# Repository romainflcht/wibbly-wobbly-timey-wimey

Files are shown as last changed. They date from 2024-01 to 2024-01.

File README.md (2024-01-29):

# Wibbly-Wobbly-Timey-Wimey

<p align="center">
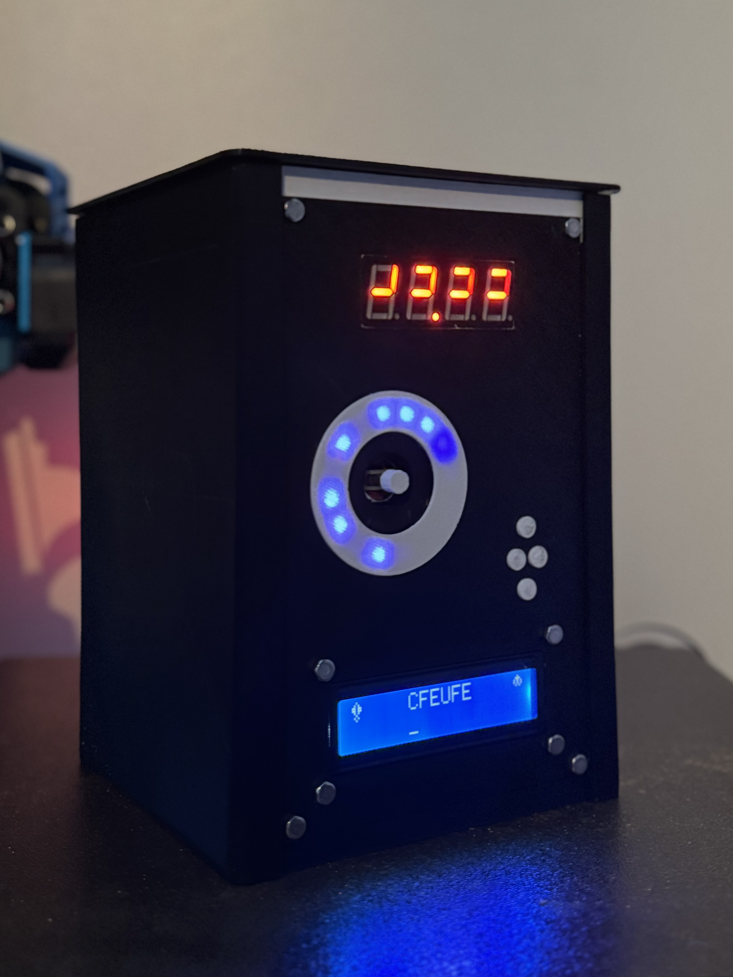
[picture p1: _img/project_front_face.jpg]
A picture of the project
  
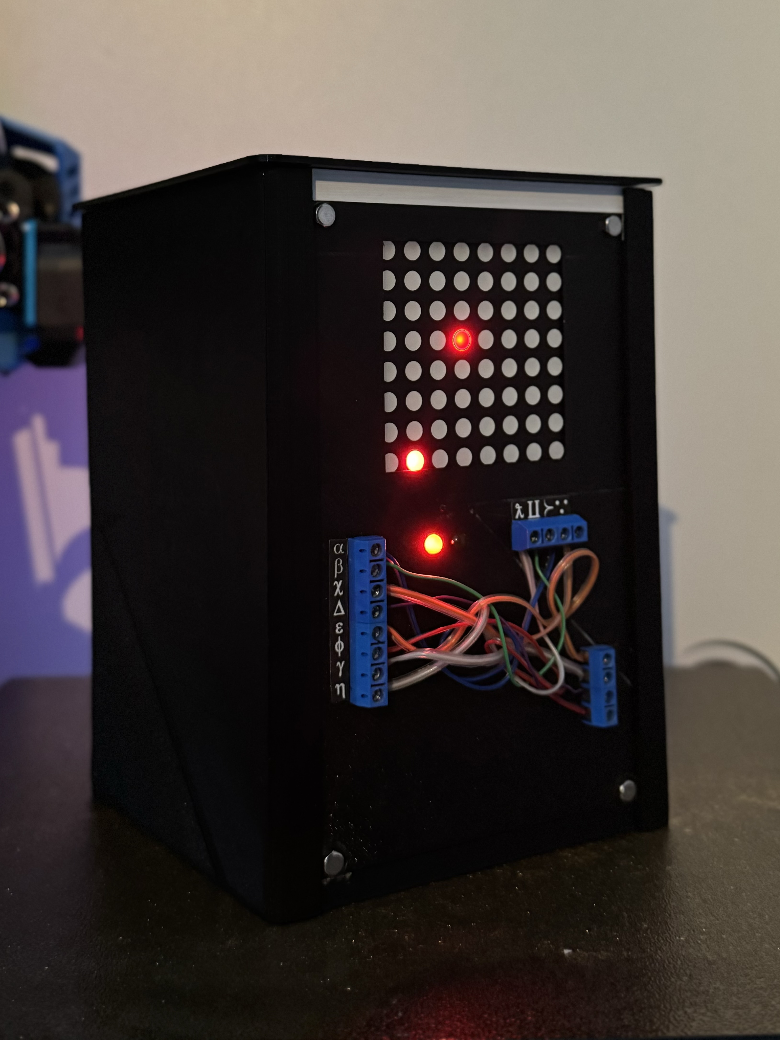
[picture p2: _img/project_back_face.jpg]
A picture of the project
  
  <br />
  <i>The TARDIS that need to be defused.</i>
</p>
<br />

<div style="text-align: justify">
"Wibbly-Wobbly Timey-Wimey" is a bomb defusal escape game inspired by the popular television series <a href="https://fr.wikipedia.org/wiki/Doctor_Who" target="_blank">Doctor Who</a>. This game draws inspiration from the mechanics of <a href="https://keeptalkinggame.com/" target="_blank">Keep Talking And Nobody Explodes</a>. The primary objective of our game is to defuse the TARDIS by solving four small puzzles within a 45-minute time limit. To assist players in resolving these puzzles, the game includes a documentation guide.
</div>

## The project
<div style="text-align: justify">
This project is an engineering school assignment completed over one semester in groups of three. The instructions for this project were to create something playable, drawing inspiration from a movie or a series. Given my strong interest in escape games, the idea of developing a game similar to <a href="https://keeptalkinggame.com/" target="_blank">KTaNE</a> quickly crossed my mind. The challenge, however, was to connect this concept with a movie. Fortunately, one member of our group was a passionate fan of Doctor Who, and that's when the project truly took off!
</div>

## How to play
<div style="text-align: justify">
The game is designed to be played by two players: one manipulating the bomb, and the other reading the manual. Both players can see the bomb and the manual. If you want to increase the difficulty, you can play separately, with one person handling the bomb and the other reading the manual.
</div>

## The defuse manual
<div style="text-align: justify">
The manual and page layout were entirely created by my two friends. I'm not really proficient with Word and Doctor Who... Here is the manual:
</div>

- [Wibbly-Wobbly Timey-Wimey Manual.pdf](MANUAL/Wibbly-Wobbly_Timey-Wimey_Manual.pdf)

# Puzzle description and working principle

<p align="center">
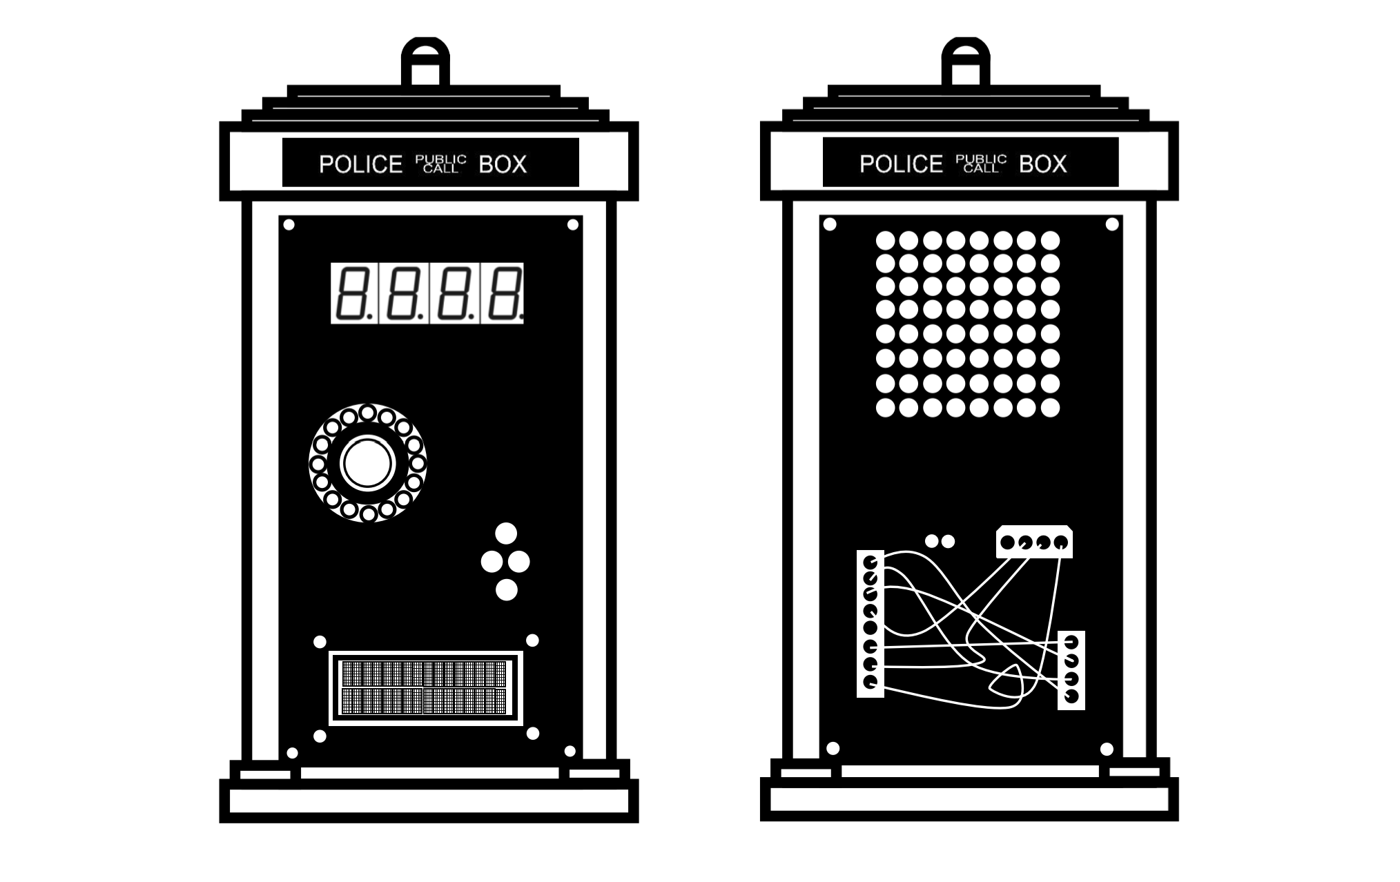
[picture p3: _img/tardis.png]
Schematic of the TARDIS
  
  <br />
  <i>Schematic of the TARDIS.</i>
</p>

<div style="text-align: justify">
The game is composed of 4 defusable puzzles that need to be defused to win the game. Each puzzle is independent of the others, and every solution is in the manual.

<br /><br />
<p align="center">
  The electronic components of the TARDIS
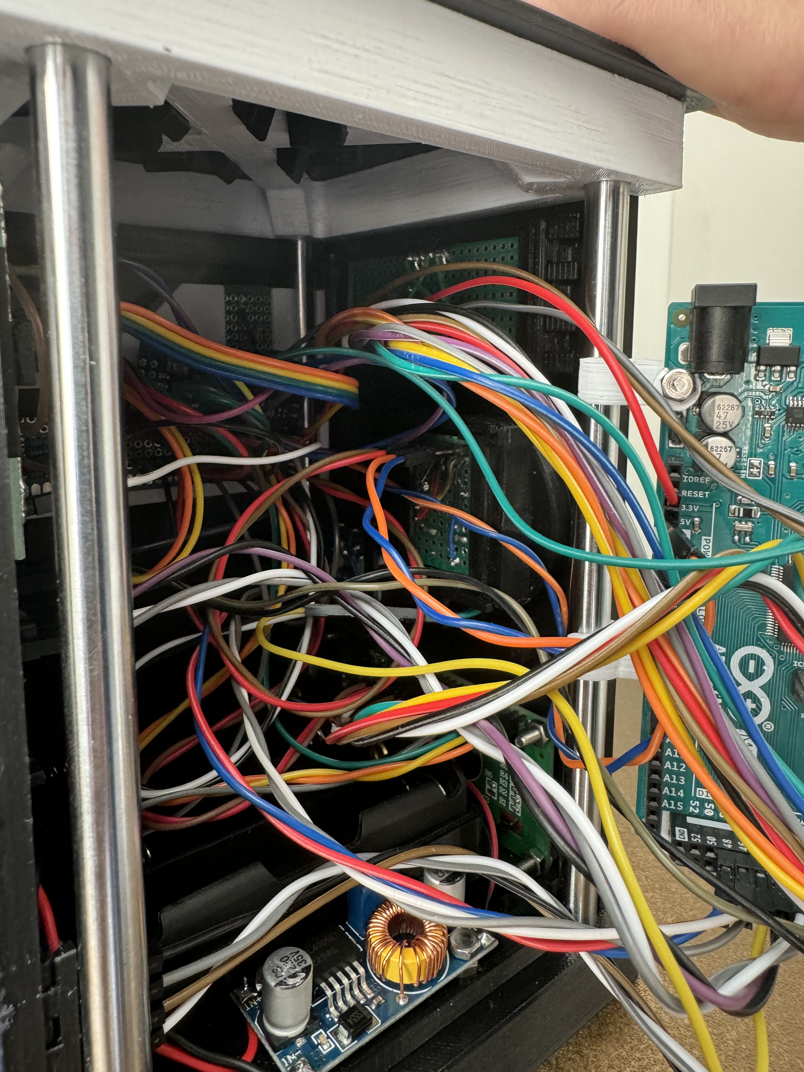
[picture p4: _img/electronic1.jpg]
The electronic components of the TARDIS
  
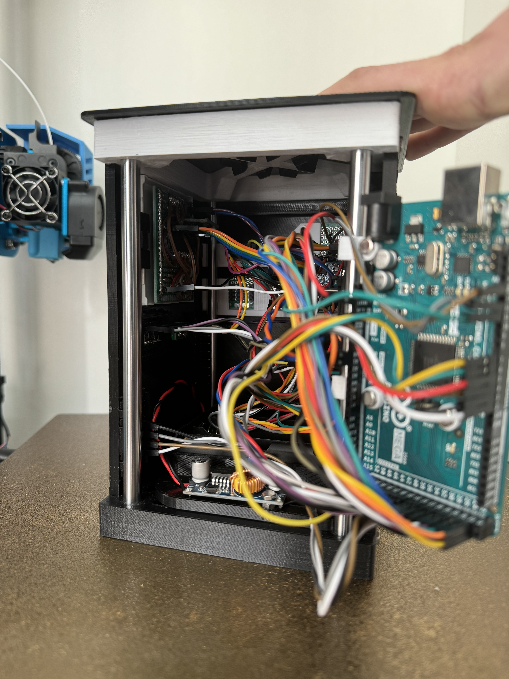
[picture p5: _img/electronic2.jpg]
The electronic components of the TARDIS
  
  <br />
  <i>The electronic components of the TARDIS.</i>

</p>
<br />

This project uses an Arduino MEGA as the main microcontroller. Each module consists of a custom-made electronic circuit soldered onto perfboard. The entire system is powered by four lithium-ion 18650 batteries arranged in series, allowing the project to run continuously for 45 minutes.
</div>

## The Timer
<p align="center">
    <video style="border-radius: 5px; max-height: 300px;" autoplay muted loop controls>
    <source src="_img/timer.mp4" type="video/mp4">
    </video>
</p>

<div style="text-align: justify">
The timer module is a simple 4-digit 7-segment display that indicates the remaining time of the game.
</div>

## The Joystick
<p align="center">
    <video style="border-radius: 5px; max-height: 300px;" autoplay muted loop controls>
    <source src="_img/joystick.mp4" type="video/mp4">
    </video>
</p>

<div style="text-align: justify">
The joystick puzzle consists of a joystick and a 16-LED ring that displays a binary code. Based on the code shown by the ring, the user needs to identify the correct directional sequence in the manual and replicate it on the joystick to solve and unlock the puzzle.
</div>

## The LCD
<p align="center">
    <video style="border-radius: 5px; max-height: 300px;" autoplay muted loop controls>
    <source src="_img/lcd.mp4" type="video/mp4">
    </video>
</p>

<div style="text-align: justify">
The LCD puzzle consists of an LCD screen and four buttons. Two symbols and a group of letters are displayed on the LCD. The user needs to decipher the word based on the two symbols, using the manual to unlock this puzzle.
</div>

## Wires
<p align="center">
  wire module
  <br />
</p>

<div style="text-align: justify">
To unlock this puzzle, you need to cut the correct combination of wires, as indicated in the manual. Be careful, as cutting a wire that was not meant to be cut will lock the puzzle forever! :D 
</div>

## The Gyroscope
<p align="center">
    <video style="border-radius: 5px; max-height: 300px;" autoplay muted loop controls>
    <source src="_img/gyro.mp4" type="video/mp4">
    </video>
</p>

<div style="text-align: justify">
The gyroscope module is pretty easy to defuse. You need to rotate the TARDIS to move a dot on the LED matrix. This dot needs to be placed on the other static dot to validate a step. You will need to do this 5 times to defuse this module.
</div>

# 3D Project
<p align="center">
    <video style="border-radius: 5px; max-height: 300px;" autoplay muted loop controls>
    <source src="_img/3D_project_build.mp4" type="video/mp4">
    </video>
</p>

<div style="text-align: justify">
The structure of the project is entirely 3D printed using a Sidewinder X1 and a Wanhao D12. One of the instructions for this project was that it needed to be demountable, so we couldn't use glue to attach components or anything (I really don't like glue anyway, ahah!).
</div>

## The base
<p align="center">
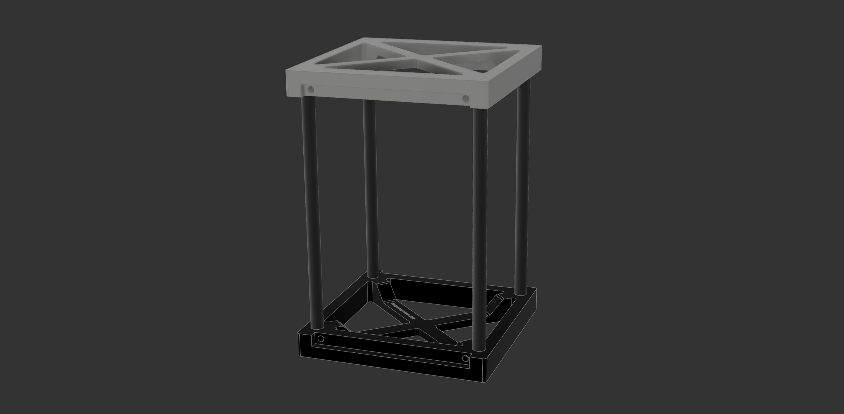
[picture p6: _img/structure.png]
3D model of base structure
  
  <br />
  <i>3D model of the TARDIS base structure.</i>
</p>
<br />
<div style="text-align: justify">
The main structure of the TARDIS consists of two identical bases held together by four metal rods cut to size and press-fitted inside four holes in those bases. This structure is exceptionally strong and can support my weight (70 kg) in compression, and likely even more.
</div>

## Each faces
<p align="center">
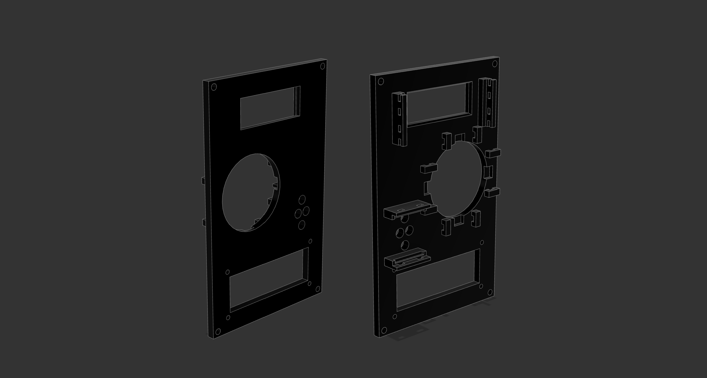
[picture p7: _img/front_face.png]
3D model of the front face
  
  <br />
  <i>3D model of the TARDIS front face.</i>
  <br />
  <br />
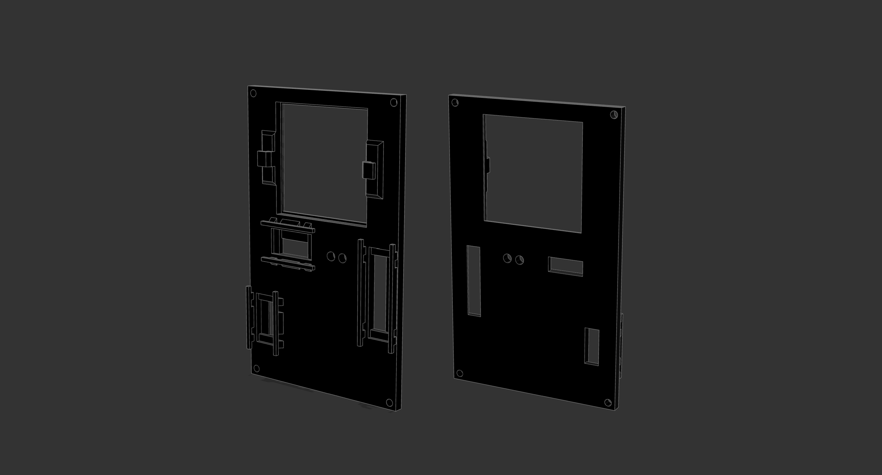
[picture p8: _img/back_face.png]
3D model of the back face
  
  <br />
  <i>3D model of the back TARDIS back face.</i>
</p>
<br />

<div style="text-align: justify">
Every module is distributed on the front and back surfaces of the TARDIS. Designing these surfaces was a nightmare, as each module had to fit into a very tight space. Additionally, we had to incorporate our clipping mechanism to ensure that everything securely holds onto these surfaces.
</div>

## Clipping method
<div style="text-align: justify">
Since glue was forbidden, I had to come up with an idea to secure every custom-made perfboard to the front and back faces. The initial concept involved creating small chamfers to insert the perfboard and secure it in place using clips. This method worked quite well for a single attachment, but after removing the board, the chamfers tended to wear out, rendering them ineffective for subsequent uses.

<br />
<p align="center">
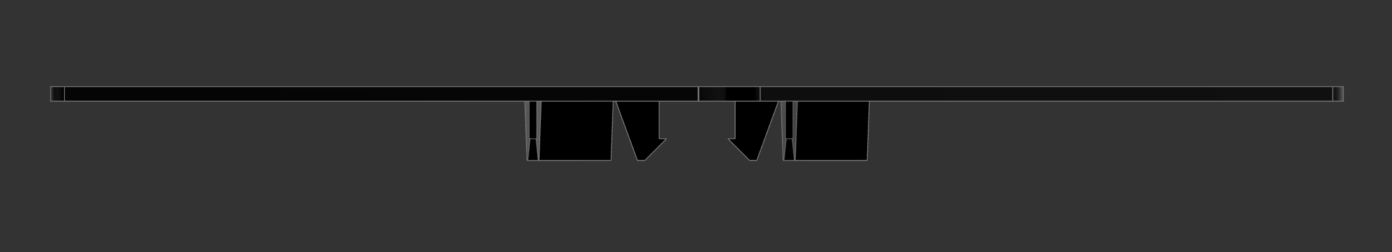
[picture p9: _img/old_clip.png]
The abandonned clipping method
  
  <br />
  <i>The abandonned clipping method. </i>
</p>

I didn't like the idea of reprinting a 6-hour-long piece just because one clip is worn. So I came up with another idea. Each board is held in place by small 3D printed pieces that fit into notches.

<p align="center">
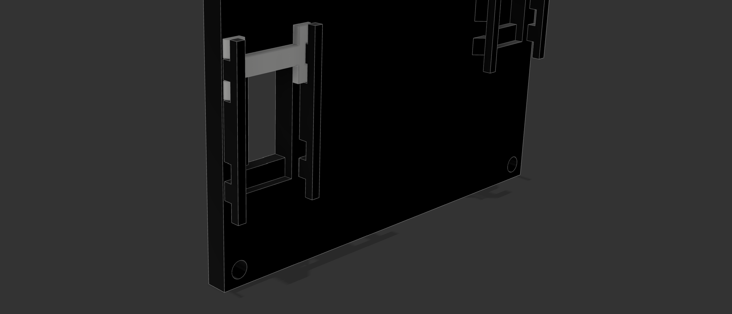
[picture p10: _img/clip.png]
The really good clipping method
  
  <br />
  <i>The really good (clever? 🫣) clipping method. </i>
</p>

Here is one of those pieces that is heated to become deformable, allowing us to install it inside those notches. Once installed, we let these pieces cool down and regain their stiffness. And TADAAAA! In the event that we need to remove a module, we can cut these small pieces with a cutting plier. If we want to reinstall the module, one piece takes up to three minutes to print (Wayyyy better than 6 hours), making it possible to reinstall the module.
</div>

# Conclusion
<div style="text-align: justify">
This project is by far the most advanced I have undertaken so far. I truly enjoyed imagining puzzles and bringing them to life using electronics and code. Additionally, we received a really good grade for this project! :D
</div>

# Licence
- romainflcht

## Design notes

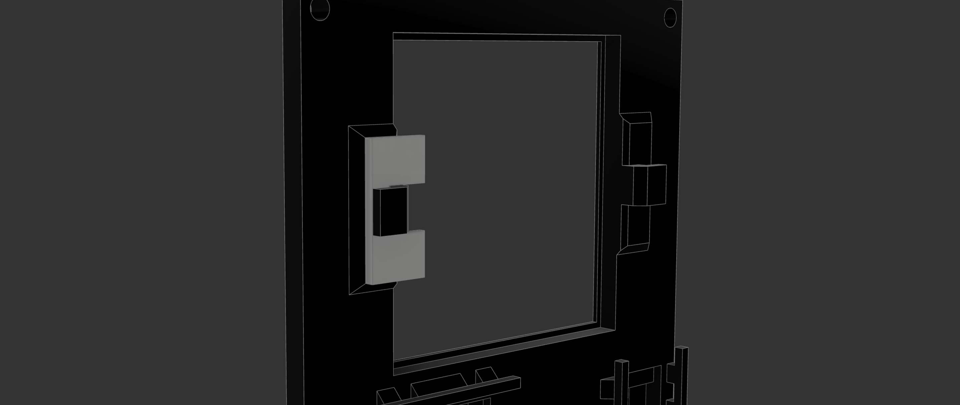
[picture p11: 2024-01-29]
_img/clip2.png

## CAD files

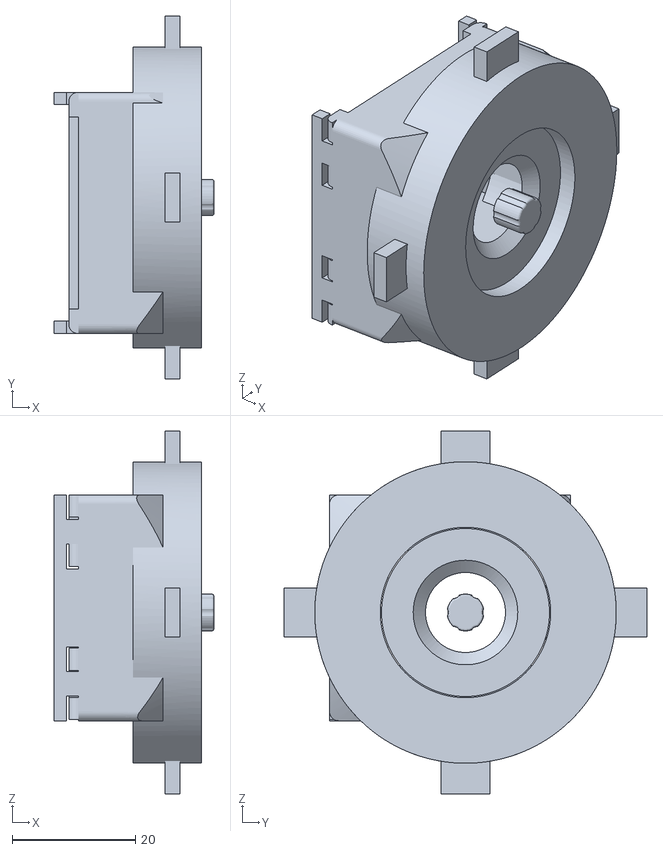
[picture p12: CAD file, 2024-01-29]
3D_MODELS/joystick_assembly.stl
26.0 x 59.0 x 59.0

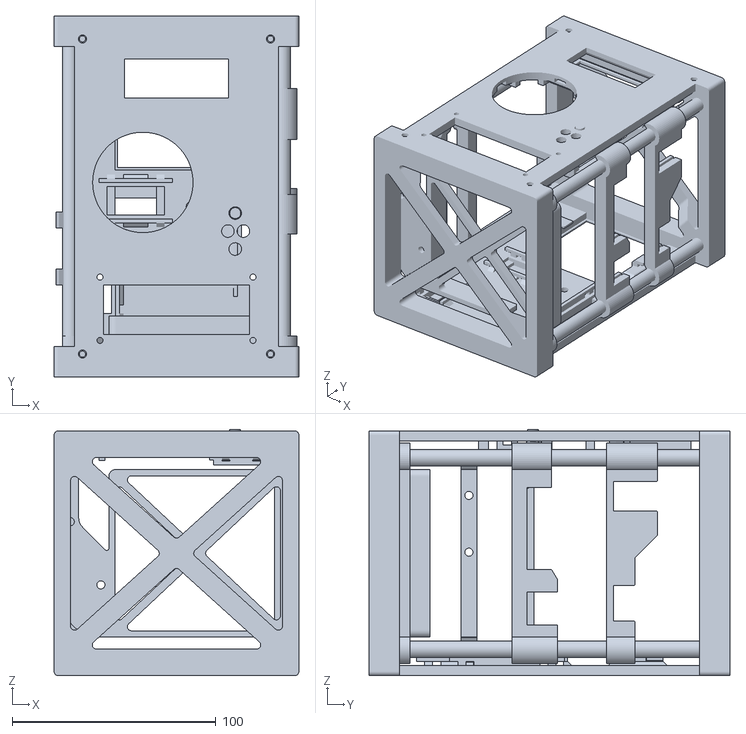
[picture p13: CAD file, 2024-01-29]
3D_MODELS/project_assembly.stl
120.0 x 177.0 x 120.8

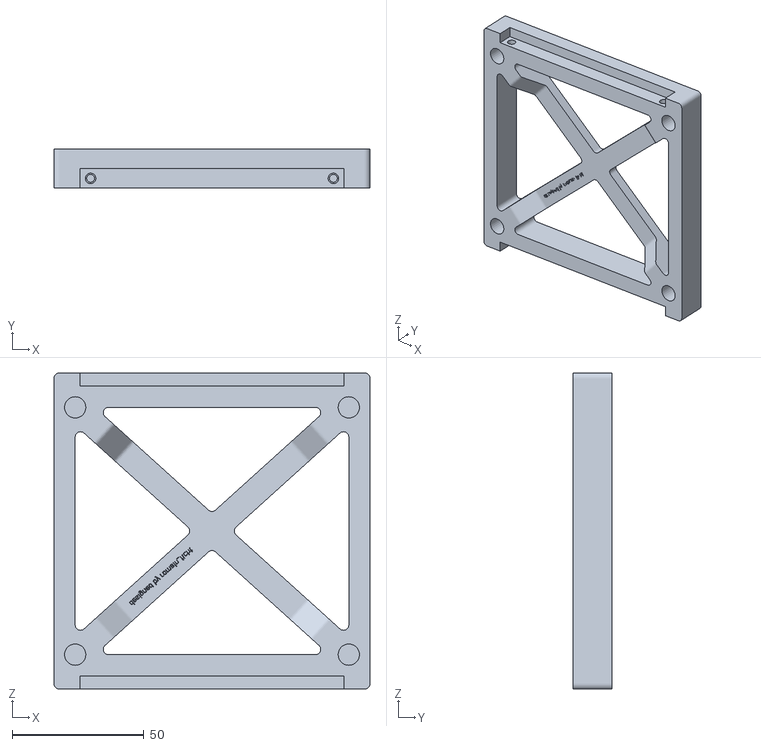
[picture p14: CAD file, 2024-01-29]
3D_MODELS/top_body.stl
120.0 x 15.0 x 120.0

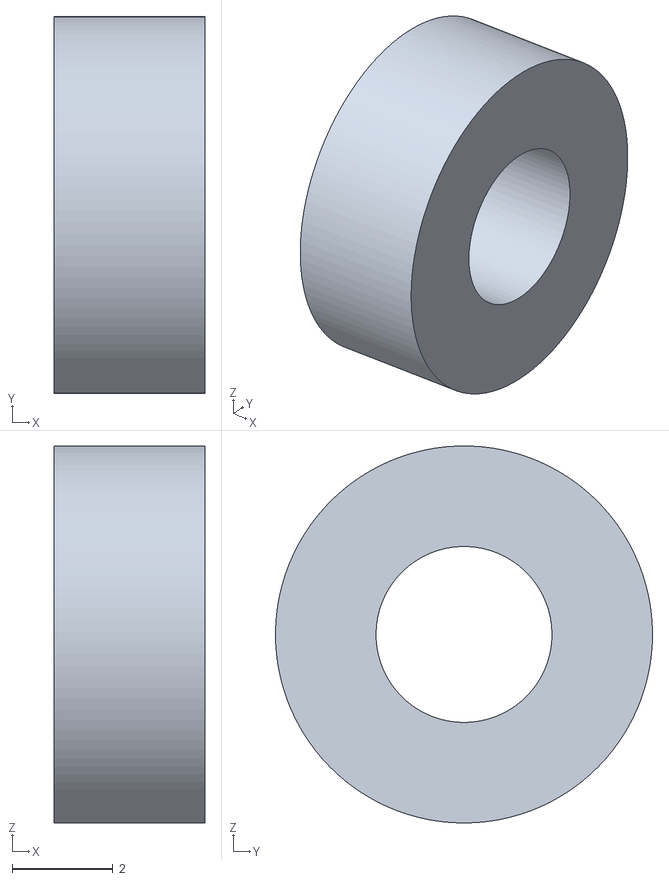
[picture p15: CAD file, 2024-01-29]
3D_MODELS/motherboard_spacer.stl
3.00 x 7.50 x 7.50

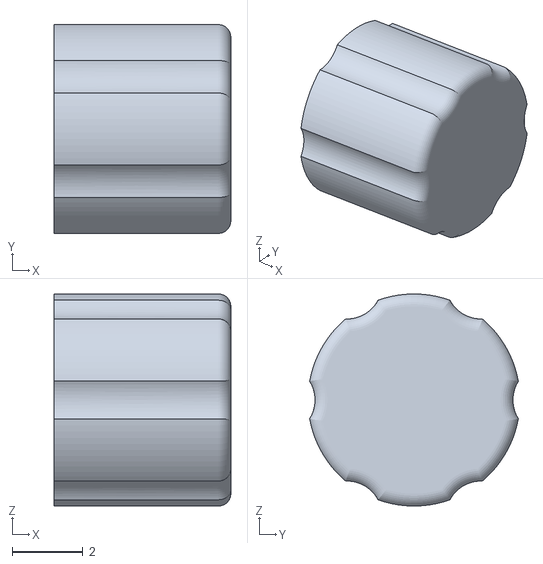
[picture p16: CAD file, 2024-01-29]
3D_MODELS/joystick_tip.stl
5.00 x 5.91 x 6.00

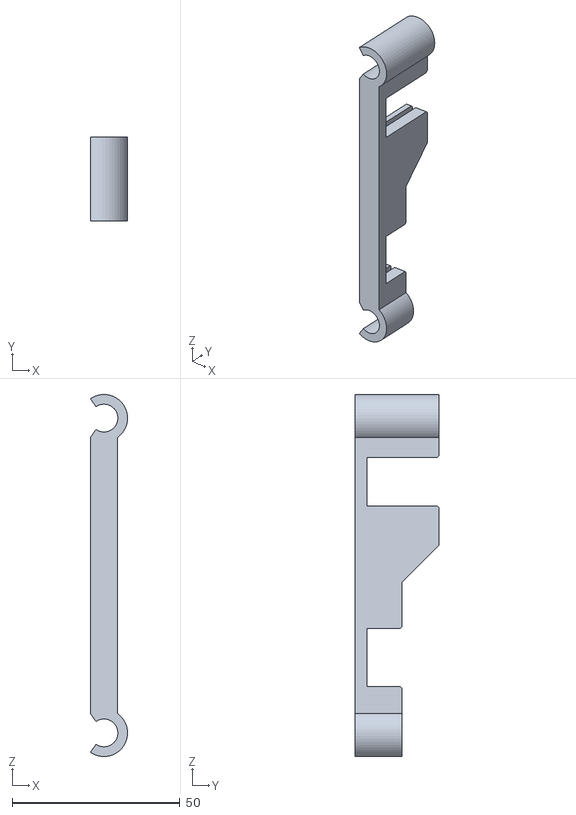
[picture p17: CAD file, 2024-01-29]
3D_MODELS/resistor_buzzer_bar.stl
11.1 x 25.0 x 108.0

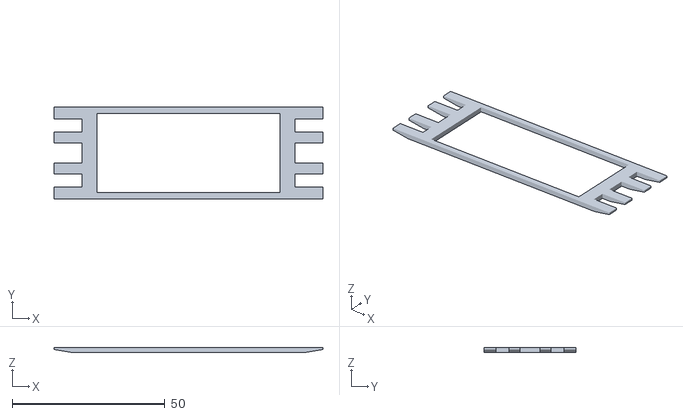
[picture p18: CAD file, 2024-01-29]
3D_MODELS/timer_clip.stl
88.0 x 30.0 x 1.70

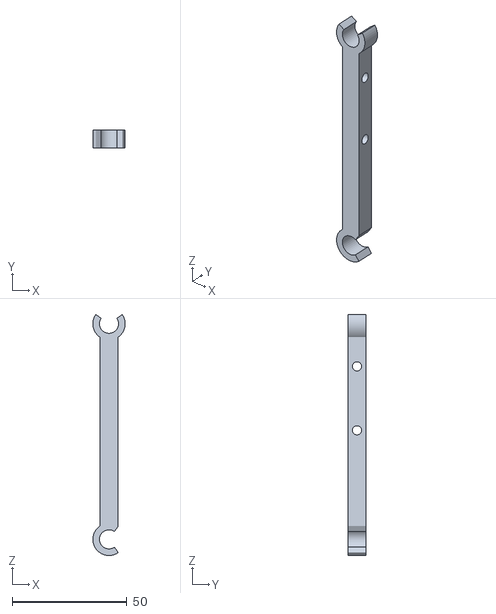
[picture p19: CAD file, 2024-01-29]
3D_MODELS/mother_board_top_bar.stl
14.1 x 8.00 x 105.0

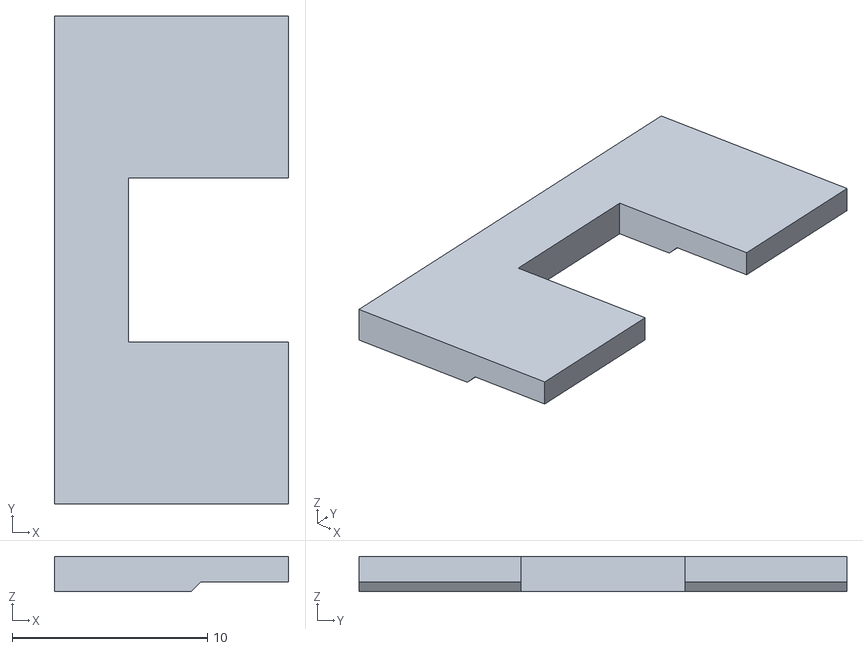
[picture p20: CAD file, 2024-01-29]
3D_MODELS/matrix_clip.stl
12.0 x 25.0 x 1.80

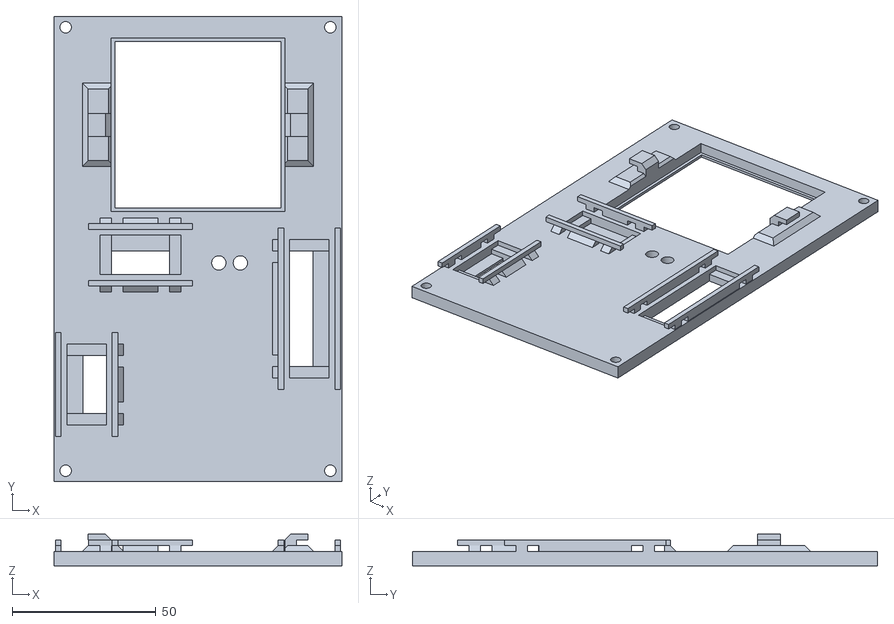
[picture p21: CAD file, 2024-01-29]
3D_MODELS/back_face.stl
100.2 x 162.0 x 11.0

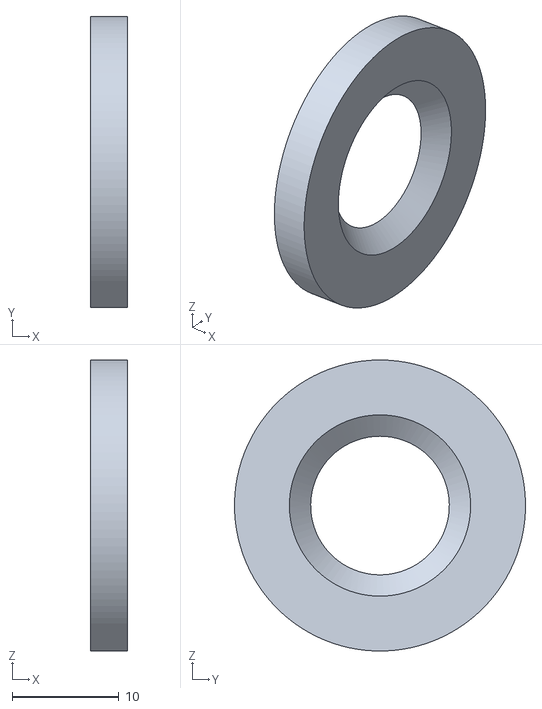
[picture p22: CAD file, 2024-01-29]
3D_MODELS/joystick_cover.stl
3.50 x 27.3 x 27.3

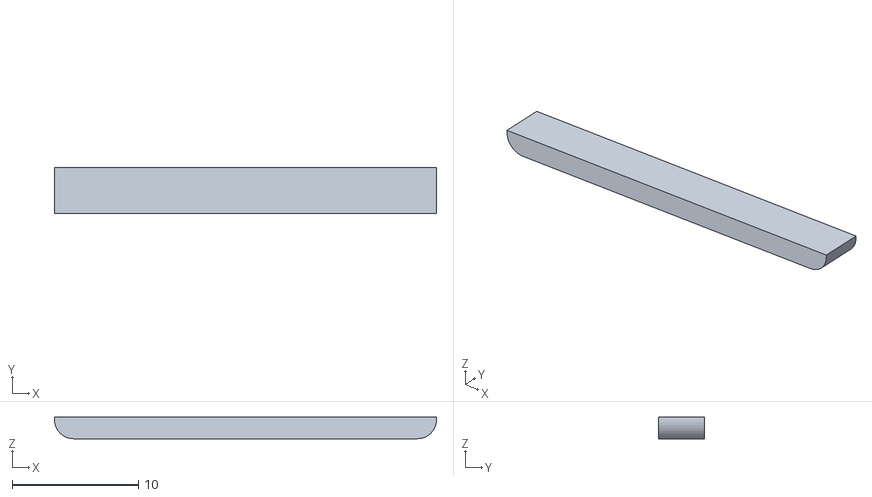
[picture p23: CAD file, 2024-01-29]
3D_MODELS/joystick_slide.stl
30.2 x 3.60 x 1.70

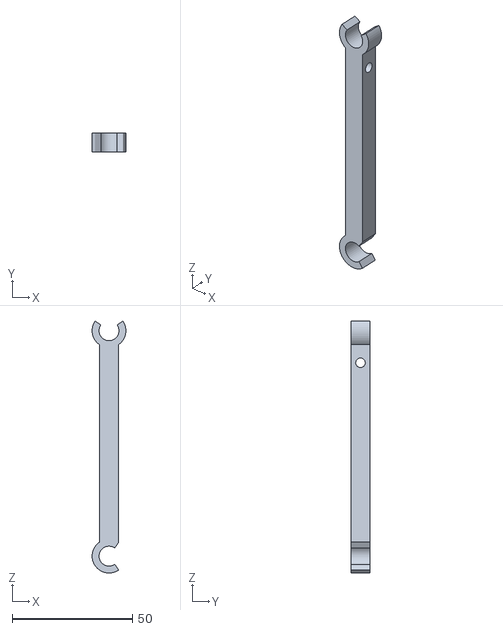
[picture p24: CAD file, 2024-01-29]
3D_MODELS/mother_board_bottom_bar.stl
14.1 x 8.00 x 105.0

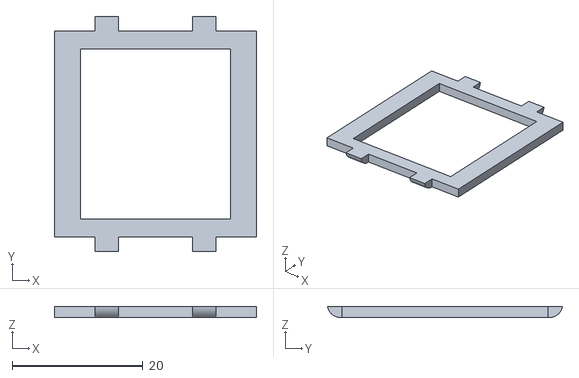
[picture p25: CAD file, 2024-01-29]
3D_MODELS/lcd_btn_clip.stl
31.0 x 36.0 x 1.70

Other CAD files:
3D_MODELS/bottom_body.stl
3D_MODELS/front_face.stl
3D_MODELS/clip.stl
3D_MODELS/joystick_module.stl
3D_MODELS/alim_bar.stl
3D_MODELS/battery_holder.stl
3D_MODELS/button.stl
3D_MODELS/joystick_clip.stl
3D_MODELS/led_diffuser.stl
3D_MODELS/top_cover.stl

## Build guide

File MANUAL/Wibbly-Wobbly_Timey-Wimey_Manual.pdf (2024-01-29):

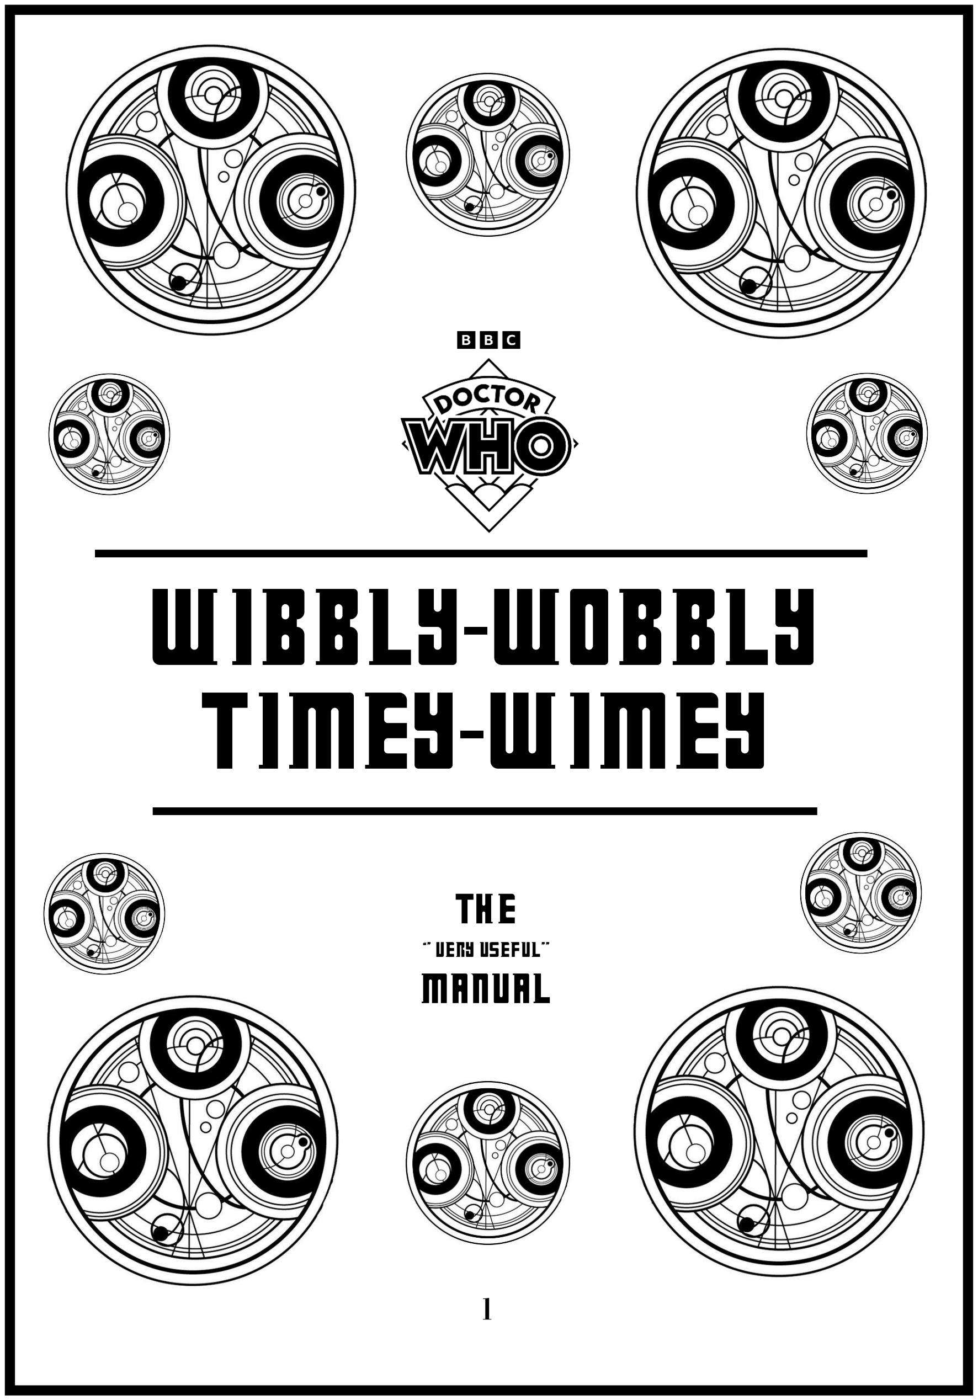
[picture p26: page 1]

1

# Wibbly-Wobbly Timey-Wimey

## The

“”Very useful””

## Manual

2

End User License Agreement (EULA) for "Wibbly-Wobbly Timey-Wimey"

This End User License Agreement ("Agreement") is a legal contract between you ("User") and OSVC.co, the creator and owner of the game "Wibbly-Wobbly Timey-Wimey." By accessing, or using Wibbly-Wobbly Timey-Wimey, you agree to be bound by the terms and conditions outlined in this Agreement.

### 1. License Grant:

Subject to compliance with this Agreement, OSVC.co grants the User a non-exclusive, non-transferable, revocable license to use Wibbly-Wobbly Timey-Wimey for personal, non-commercial purposes.

### 2. Age Restriction:

Users must be at least 12 years old to use Wibbly-Wobbly Timey-Wimey. Users under the age of 18 may use the game only with the involvement and consent of a parent or legal guardian.

### 3. Account and Registration:

Users are required to create an account to access Wibbly-Wobbly Timey-Wimey. All information provided during registration must be accurate and kept up-to-date. Users are responsible for maintaining the confidentiality of their account credentials.

### 4. Code of Conduct:

Users agree to abide by a code of conduct that prohibits disruptive behaviour, harassment, cheating, and any violation of the terms outlined in this Agreement. (Respect the TARDIS, it is a living being.)

### 5. Intellectual Property:

All intellectual property rights in Wibbly-Wobbly Timey-Wimey, including but not limited to graphics, audio, and text, are owned by OSVC.co. Users agree not to reproduce, distribute, or create derivative works based on Wibbly-Wobbly Timey-Wimey.

### 6. Privacy:

OSVC.co collects and processes personal information in accordance with its privacy policy. Users should review the privacy policy to understand how their data is handled.

3

7.Updates and Maintenance:
OSVC.co may release updates or perform maintenance on Wibbly-Wobbly Timey-Wimey. Users are responsible for ensuring that they have the latest version of the game. (It means you must buy it (again).)

### 8. Termination:

OSVC.co reserves the right to terminate or suspend a user's access to Wibbly-Wobbly Timey-Wimey for violations of this Agreement or for any reason, at its sole discretion. (Yes, we can.)

### 9. Limitation of Liability:

To the fullest extent permitted by law, OSVC.co shall not be liable for any direct, indirect, incidental, special, or consequential damages arising out of or in connection with the use or inability to use Wibbly-Wobbly Timey-Wimey.

### 10. Governing Law:

- This Agreement is governed by and construed in accordance with the laws of the Earth. Any disputes arising out of or in connection with this Agreement shall be resolved through binding arbitration.

Disclaimer:
Wibbly-Wobbly Timey-Wimey is a fictional game created by OSVC.co. We are not affiliated with the BBC or "Doctor Who." This game is designed purely for entertainment and fun, and any resemblance to other entities is purely coincidental.
By using Wibbly-Wobbly Timey-Wimey, the User acknowledges that they have read, understood, and agree to be bound by the terms and conditions of this Agreement. If the User does not agree, they should not install, access, or use Wibbly-Wobbly Timey-Wimey.

4

* * *

Before we start, here is a bit of knowledge for your own culture,

The history of Doctor Who is a remarkable journey through time and space that has captivated audiences for decades. Born out of the creative genius of Sydney Newman, C. E. Webber, and Donald Wilson, Doctor Who made its debut on the BBC on November 23, 1963. This iconic science fiction series was envisioned as a family-oriented show that would blend education and entertainment, taking viewers on adventures that spanned across galaxies and centuries.

The character of the Doctor, a Time Lord from the planet Gallifrey, was brilliantly portrayed by William Hartnell in the early years. The Doctor, an enigmatic and eccentric figure, possessed the unique ability to regenerate, allowing for different actors to take on the role over the years. This narrative device not only kept the character fresh but also ensured the show's longevity.

The early years of Doctor Who introduced audiences to the Doctor's grandchild, Susan Foreman, and two teachers, Ian Chesterton, and Barbara Wright. Together, they explored time and space in the TARDIS, a time-traveling ship that outwardly resembled a British police box. The Daleks, iconic adversaries resembling armoured pepper shakers, made their debut during this era and quickly became synonymous with the series.

In 1966, the show faced a pivotal moment when William Hartnell's health declined. This led to the introduction of the concept of regeneration, with Patrick Troughton stepping into the role. This bold move not only saved the show but became one of its defining features.

Over the years, Doctor Who evolved, introducing various companions, and facing ever more formidable adversaries. Jon Pertwee's Doctor, characterized by his flamboyant attire and reliance on technology, navigated the challenges of the 1970s. Tom Baker's portrayal, the longest in the show's history, brought a whimsical yet profound dimension to the character.

5

The 1980s brought about more changes, with Peter Davison, Colin Baker, Sylvester McCoy, and Paul McGann taking on the role of the Doctor. The series faced challenges, including a brief hiatus, but ultimately returned stronger than ever in 2005 under the guidance of Russell T Davies. Christopher Eccleston, David Tennant, and Matt Smith played the role of the Doctor during this period, each bringing their unique style to the character.

The revival of Doctor Who not only embraced modern storytelling techniques but also introduced a new generation of fans to the wonders of the TARDIS. The show delved into complex characters, intricate story arcs, and emotional depth while maintaining its roots in science fiction and adventure.

Peter Capaldi and Jodie Whittaker continued the legacy as the Twelfth and Thirteenth Doctors, respectively. Jodie Whittaker made history as the first woman to portray the Doctor, breaking new ground and inspiring a diverse audience.

In the grand commemoration of its 60th anniversary this year, the iconic show is set to delight fans with a special celebration. Adding to the excitement, the beloved David Tennant, a fan favourite, returns to the helm as the all-new 14th Doctor. However, the festive season brings an additional treat as Ncuti Gatwa is poised to take on the mantle of the 15th Doctor for this Christmas, promising viewers a memorable and thrilling continuation of the show's rich legacy.

Doctor Who's impact extends beyond television, influencing literature, audio dramas, and spin-off series. The show's imaginative storytelling and exploration of morality, ethics, and the consequences of time travel have solidified its place in the hearts of fans worldwide.

As Doctor Who celebrates its remarkable journey through time and space, it remains a testament to the enduring power of storytelling and the boundless possibilities of the human imagination. The Doctor's adventures continue, promising new tales, new companions, and new worlds to explore for generations to come.

6

## THE CONTEXT

The Doctor has been captured by the Celestial Toymaker, an all-powerful entity who delights in imprisoning its victims in games where their freedom is at stake. However, be careful, the Toymaker despises losing, and the games are always rigged in his favour.

The Toymaker has used his powers to trigger an explosion aboard the Doctor's TARDIS. Now, the fate of the universe hinges on the success of this diabolical game. The Toymaker has set a simple condition: solve all his puzzles in less than 45 minutes. If the Doctor fails, the TARDIS will explode, irreversibly dooming our universe.

But the Toymaker is cunning. He has ensured that the puzzles can only be accessed from outside the spaceship and has reduced the TARDIS to miniature size, preventing the Doctor from escaping. Faced with this desperate situation, the Doctor decided to land somewhere on Earth, and this is where your role comes into play! As the Doctor's companion, it is up to you to help solve the puzzles, thwart the Toymaker's traps, and prevent the end of the universe as we know it.

7

Welcome to the dangerous and challenging world of Wibbly-Wobbly Timey-Wimey. Study this manual carefully; you are the expert. In these pages you will find everything you need to know to defuse even the most insidious trick of the Toymaker. And remember — One small oversight and it could all be over!

8

## DEFUSING THE TARDIS

The TARDIS will explode when its countdown timer reaches 0:00 or when too many strikes have been recorded. The only way to defuse the TARDIS is to disarm all its modules before its countdown timer expires.

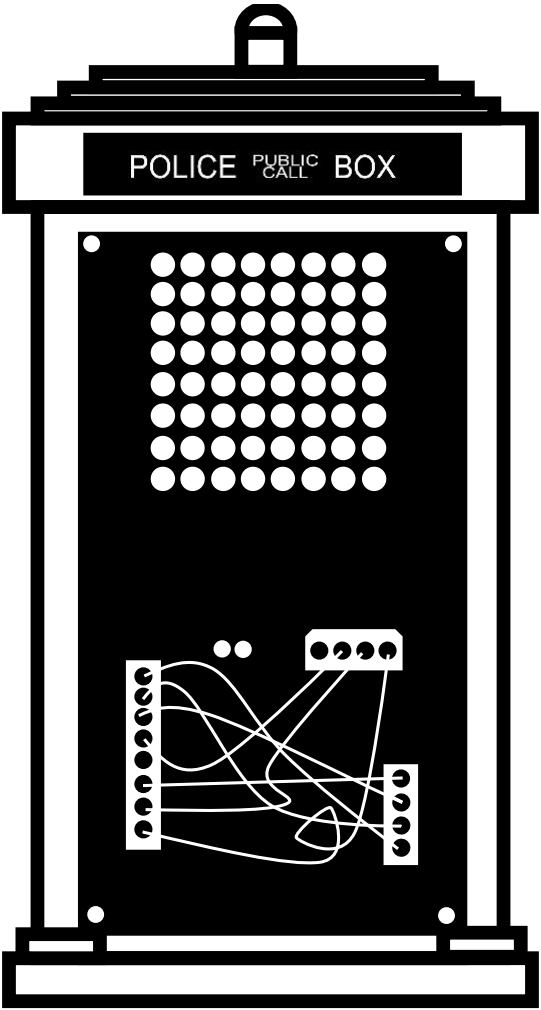
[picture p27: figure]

Modules

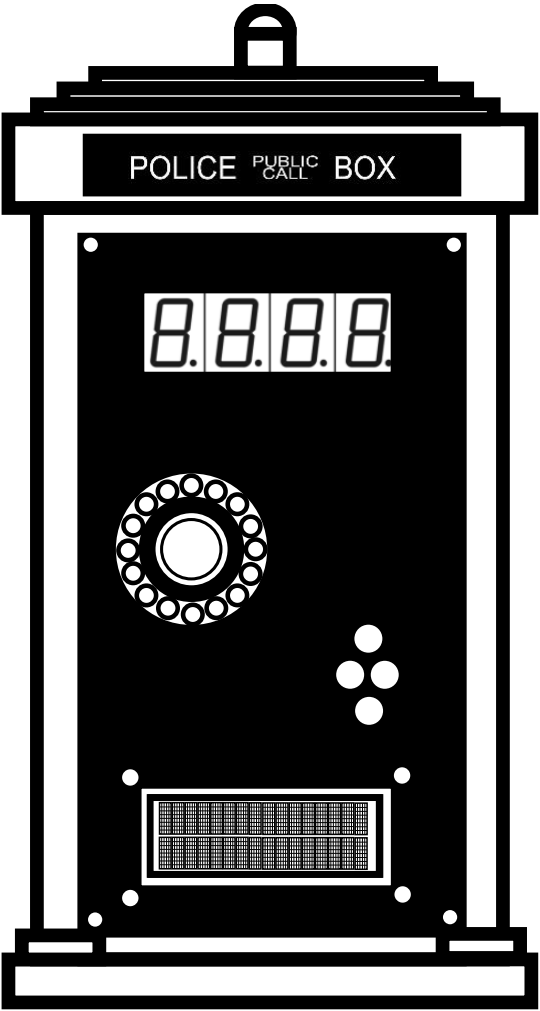
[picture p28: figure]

The TARDIS will incorporate a maximum of 5 modules, strategically concealed both on the front and rear of the box, each requiring disarming. Each module can be disarmed in any order. Instructions for disarming modules can be found in the following instructions.

9

Guidelines

You are granted a 45-minutes timeframe to successfully defuse the TARDIS. If the timer reaches zero, the consequences will be dire. Beware, as each puzzle presents a formidable challenge, it is essential to note that any misstep during the disarmament process will result in a deduction of 5 minutes from the remaining time.

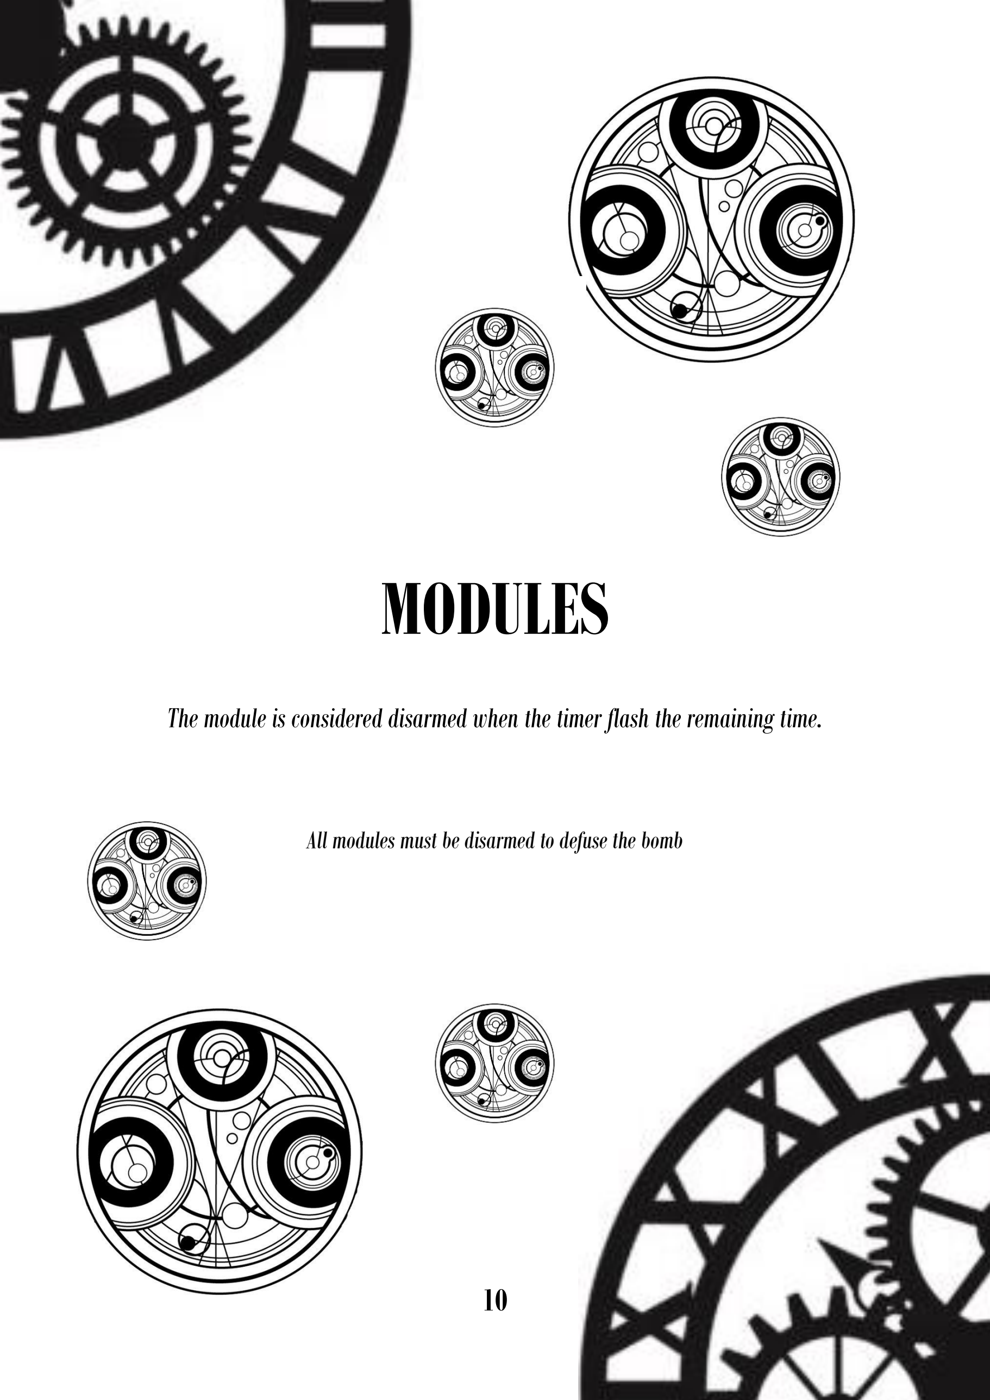
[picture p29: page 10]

10

# MODULES

The module is considered disarmed when the timer flash the remaining time.

All modules must be disarmed to defuse the bomb

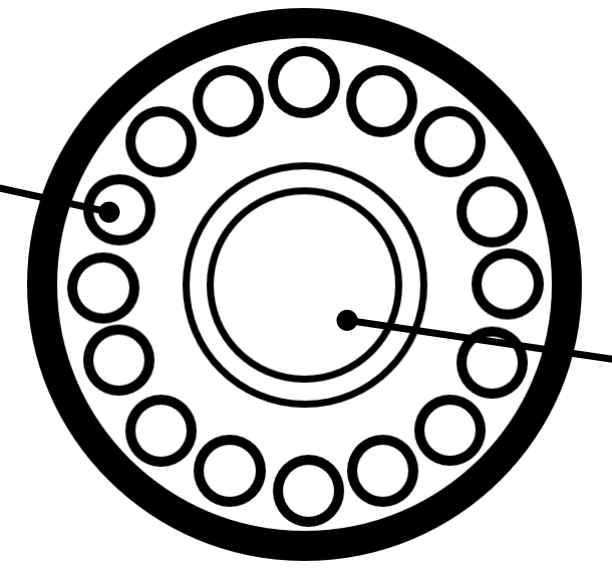
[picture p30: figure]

11

## QUANTUM CODE NEXUS

I hope you won't mix up your left and right; otherwise, things might get a bit tricky. Here's a helpful mnemonic: you have a 90% likelihood of being right-handed when writing.

To solve this puzzle successfully, you must decipher the code displayed by the RGB LED using a very precise joystick movements sequence.Follow these rules in the order they are listed, perform the first action that meets the criteria:

1. If the first 5 LED from the top, rotating counterclockwise, are blue, then orient the joystick upwards and then downwards.
2. If all illuminated LED are yellow, then orient the joystick to the right and then upwards.
3. If the first 2 LED from the bottom, rotating clockwise, are off, and the next 4 are lit in red, then orient the joystick downwards and then to the left.
4. If none of these conditions are met, I strongly recommend referring to "further instructions."

RGB LED

JOYSTICK

12

### Further Instructions

It is advisable to double-check if you are in the correct appendix; if so, here are additional instructions:

- If exactly one LED is lit in red, then refer to the table in category A.
- If exactly one LED is lit in purple, then read the displayed code clockwise and refer to the "Identification Number" appendix and then refer to the table below.
- If exactly one LED is lit in yellow, then refer to the table in category C.
- If exactly one LED is lit in green, then refer to letter C and read the direction Sequence backward.
- If exactly one LED is lit in blue, then read the displayed code counterclockwise and refer to the "Identification Number" appendix and then refer to the table below.
- If exactly one LED is lit in red, then refer to letter A.
- Otherwise, refer to category B.

Number
Dec | Hex | Category | Letter | Direction Sequence
29973 | 7515 | - | - | ↓ → ← ↓
25772 | 64AC | - | - | ← ↑ → ↑
- | 71B5 | B | - | ↑ ↑ ↓ →
128-3892 | - | A | - | ↑ ↓ → ←
4757 | - | - | - | ↑ ← → ↓
29294 | - | - | - | ↓ → ↑ →
727 | 2D7 | - | - | ← ↓ → ↑
19348 | - | - | - | ← ↓ ↑ →
2356-332 | - | B | - | → → ↑ ↓
- | - | - | A | I don’t know what to do with this one.
52578 | - | - | C | ↓ ↓ ← ←
31011 | - | - | - | → ← ↑ ↓
1004 | 3EC | - | - | → → ← ←
35933 | - | B | - | ↑ ← ↑ →
17884 | 45DC | - | - | → ↓ ↑ ←
9821 | - | - | B | If you’re reading this, it means you’requite lost.
12982 | - | C | - | → → and then ↑ ↑ or ↓ ↓, I do not know…
6818 | 1AA2 | C | - | ↑ ↑ ↓ ↓
32063 | - | - | - | ↓ ← → ↑

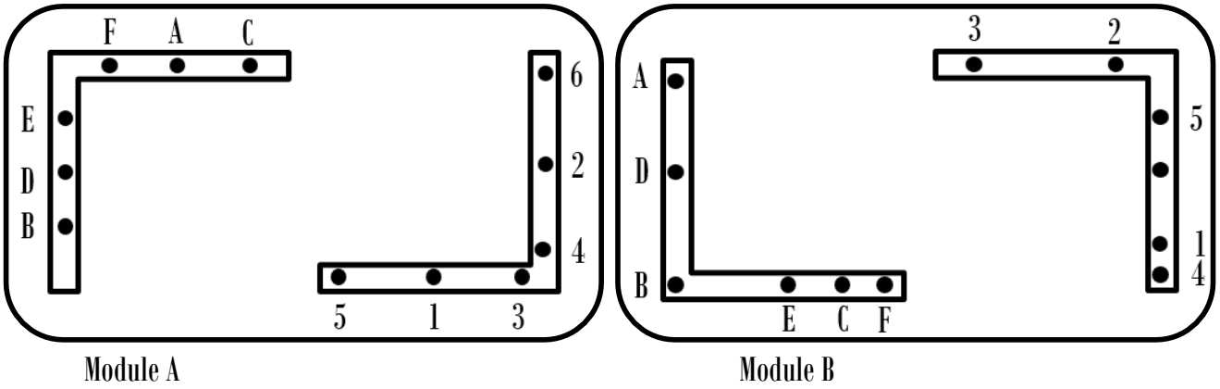
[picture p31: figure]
Module A; Module B
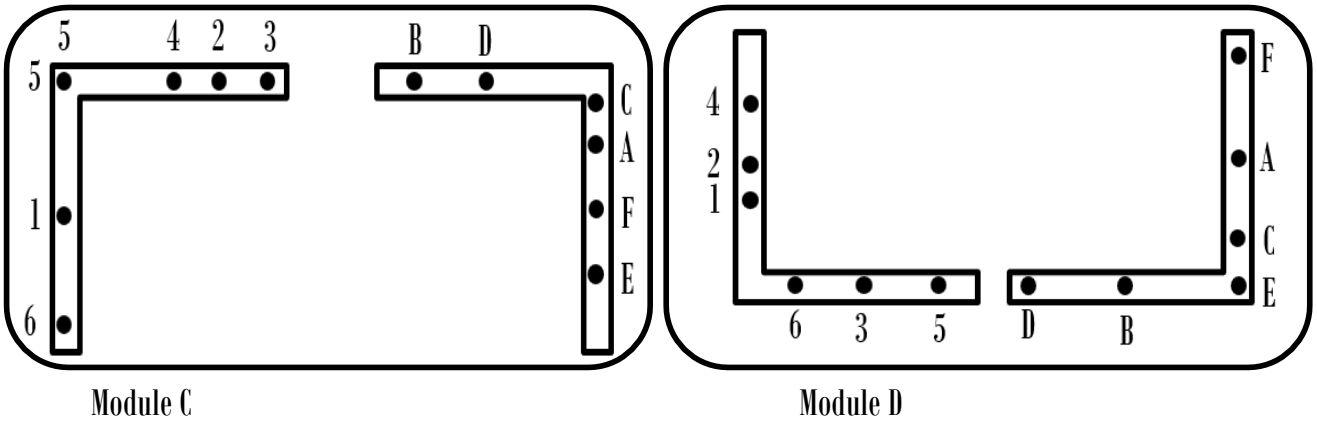
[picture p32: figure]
Module C; Module D

13

## SUPER FANTASTIC WIRE SYSTEM PRO MAX

It's just wires, but they're formidable, you'll see.

To solve these modules, you just need to read the instructions. Pay attention: I dlot uoy I'm ton doog ta ganpinlixe? lleW, siht si oging ot eb detalicspmoc.

- Decode the instructions and follow it.
- Observe the modules and choose the corresponding one.

### Step 1

Refer to Appendix 9 to ‘learn how to count’. Refer to Appendix E for ‘colour blindness detection’.

14

### Step 2

1. Module D
2. Module B
Event | Action | Instruction
-We denote A as the event "the wire
is red."
- We denote B as the event "the wire
is not blue."
- We denote C as the event "the wire is connected to a multiple of √16."
- We denote D as the event "the wire is not connected to A or B."
- We denote E as the event "the wire is not connected to C."
- We denote F as the event "the wire is connected to: lim n tends towards infinity of (2 + 6x + 19x²) / (8x² + 4x)."
- We denote 1 as the action "cut the wire connected to A."
- We denote 2 as the action "cut the wire connected to 6."
- We denote 3 as the action "do not cut."
- We denote 4 as the action "cut the wires connected to 2 and E."
- We denote 5 as the action "cut all wires except those connected to 6 and F."
- We denote 6 as the action "do nothing and wait for the bomb to explode."
- A ∩ E → 2
- B ∩ F → 5
- C ∪ B → 4
- F ∩ D → 1 ∧ 3
- A ∩ ¬ (C ∧ D) → 6

If point E is connected to an even number and the wire is red, cut the wire connected to 5.
If point A is connected to an odd number and the wire is not blue, cut the wire connected to 6. If points C and D are connected to the same number, cut the wires connected to A and B.
If point F is not connected to any number but to another letter, cut 4 wires randomly and pray. If point D is connected to 4, cut wires A, C, B, E, and F in the reverse order announced. Otherwise, reread the beginning because you have made a mistake, and the documentation is ALWAYS right.

If you feel lost, check the appendix M 'Math Base’.

15

3. Module C

Take the wires from the East to the West, passing through the North.
Red Wire | Cut if connected to: | Blue Wire | Cut if connected to: | Black Wire | Cut if connected to:
First Wire | A | First Wire | F | First Wire | E
Second Wire | C | Second Wire | D | Second Wire | B
Third Wire | E or B | Third Wire | G | Third Wire | ¬ D
4. Module A
Below, you can observe several matrix representing certain wire connection configurations. Find the correct configuration, decode the instructions, and you will have the wires to cut.
Configuration known as ‘The Tennant’ | Configuration known as ‘The Whittaker’
2 | 3 | 6 | 5 | 1 | 4
C | X
B | X
F | X
D | X
A | X
E | X
Configuration known as ‘The Capaldi’ | Configuration known as ‘The Smith’

To know which wires to cut, refer to Appendix ‘The Doctors’

A | E | F | B | D | C
1 | X
4 | X
3 | X
5 | X
2 | X
6 | X
1 | D | 4 | A | 3 | E
B | X
2 | X
C | X
5 | X
F | X
6 | X
B | D | F | 2 | 4 | 6
A | X
C | X
E | X
1 | X
3 | X
5 | X

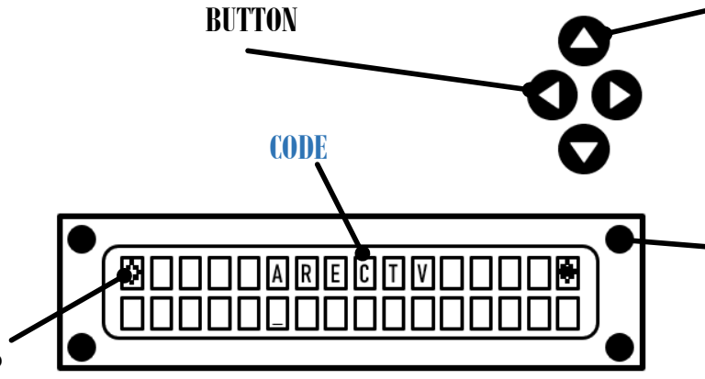
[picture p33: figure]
BUTTON; CODE

16

## PROTO ANALYTICO-DECODEX SYNTHESIS ENCRYPTION ENGINE

You will encounter a screen displaying an encoded message. Your objective is to decipher the code using a guide in the form of a table. An accompanying instruction is: "The difference between the first and the secondspecial character will give you the key." This hints at a Caesar key, where letters are shifted by a certain number. *wink-wink*
For instance, in our game, an A with a key of 5 becomes an V. The challenge lies in the fact that the table only contains special characters, and there are numbers and letters below, seemingly disordered.

## HURRY UP!

ANOTHER ONE

???

SCREW

Refer to Appendix 1: “NUMBERS IDENTIFICATION” for guidance on sorting these characters correctly. It might be a hexadecimal system. Refer to the Appendix 26: “ALPHABET” if needed.

17

### Instruction

Why are there 30 letterings when the alphabet has only 26 letters? It seems there might be an error.

A | 1A | B | 1B | C | 1C | D
1 | E | 10 | F | 2 | 4 | 6
8 | 12 | 14 | 18 | 16 | 19 | 3
7 | 5 | 9 | 11 | 13 | 17 | 15

Oh dear, there are only 28... Still, that's more than it should be.

They can take your world; they can take your heart cut you loose from all you know. But if it’s your fate then every step forward, will always be a step closer to home.

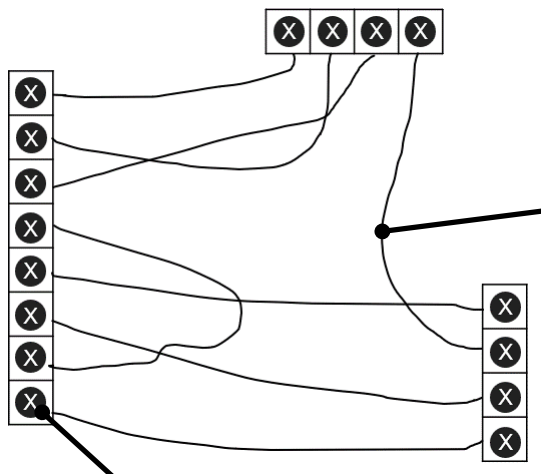
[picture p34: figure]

18

## WIRE-SNIP PRECISION MODULE

Do you know the difference between a sniper and 5 wires? You have 30sec…29…28…Noobs you don’t? Me Too lol. But do you know the difference between you and me? I don’t have a bombe to defuse…

For each symbol/color combination, refer to the two tables below to determine whether to cut the wire or not.

Letter | Instruction
X | Cut
0 | Do not Cut
R | Cut if there are 3 red wires
V | Cut or not, that the question
B | Flip a coin, if it lands on heads, cut.

Super Mega
Impressive Wire

Screw

Refer to Appendix 9 to ‘learn how to count’. Refer to Appendix E for ‘colour blindness detection’.

19

## CABLE CONNECTION CHART

This chart gives you all the information you will need to defuse this module. Why there is two tables? I don’t know… But I am pretty sure that you will do fine. The only thing I'm sure of is that if the symbol/color combination represents the configuration of the module's wires, there's definitely something to be done...

| | ꞃ | Ճ | | § | | ֎
α | X | 0 | 0 | 0 | X | X | 0
ᾀ | X | 0 | X | V | V | R | X
β | 0 | X | V | X | B | X | 0
ӂ | X | V | R | B | R | 0 | X
χ | 0 | X | V | 0 | 0 | 0 | 0
Δ | X | V | R | X | 0 | X | X
ε | X | 0 | 0 | X | 0 | V | 0
φ | 0 | X | X | 0 | V | X | X
γ | X | V | 0 | R | X | B | V
η | X | B | 0 | V | V | X | B
Table 1: first table.

Table 2: second table.

| | 𛰘 | | 𛲞 | | |
α | B | 0 | X | V | 0 | X | 0
ᾀ | R | X | 0 | X | R | V | B
β | X | 0 | X | V | B | O | 0
ӂ | X | X | R | R | X | 0 | X
χ | 0 | B | X | 0 | R | O | X
Δ | X | B | 0 | X | X | X | V
ε | X | R | X | V | X | B | X
φ | V | B | X | B | 0 | 0 | 0
γ | O | X | 0 | X | 0 | X | 0
η | X | 0 | X | B | V | X | X

20

A third one??? Why…

- | B | 0 | X | V | B
- | 0 | R | O | V | V
§ | X | O | X | V | X
- | V | V | V | R | R

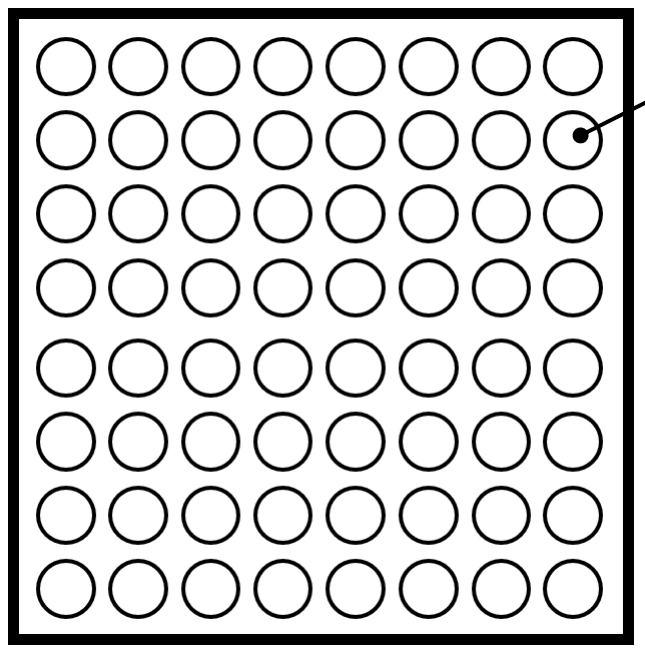
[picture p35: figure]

21

## LUXO-MATRIX DIRECTIONAL NAVIGATOR

Hint: Familiar with Bioshock? No? Well, consider purchasing it. The same recommendation applies to Outer Wilds or Baldur’s Gate 3; these games are worth acquiring. Now, how does this relate to the bomb? Not at all, but they're exceptional gaming experiences.

- Find the corresponding maze.
- The defuser must guide the red dot to the BLUE triangle, not the RED one, using their hands. But be careful if the red dot touches the wrong triangle…

LED dots

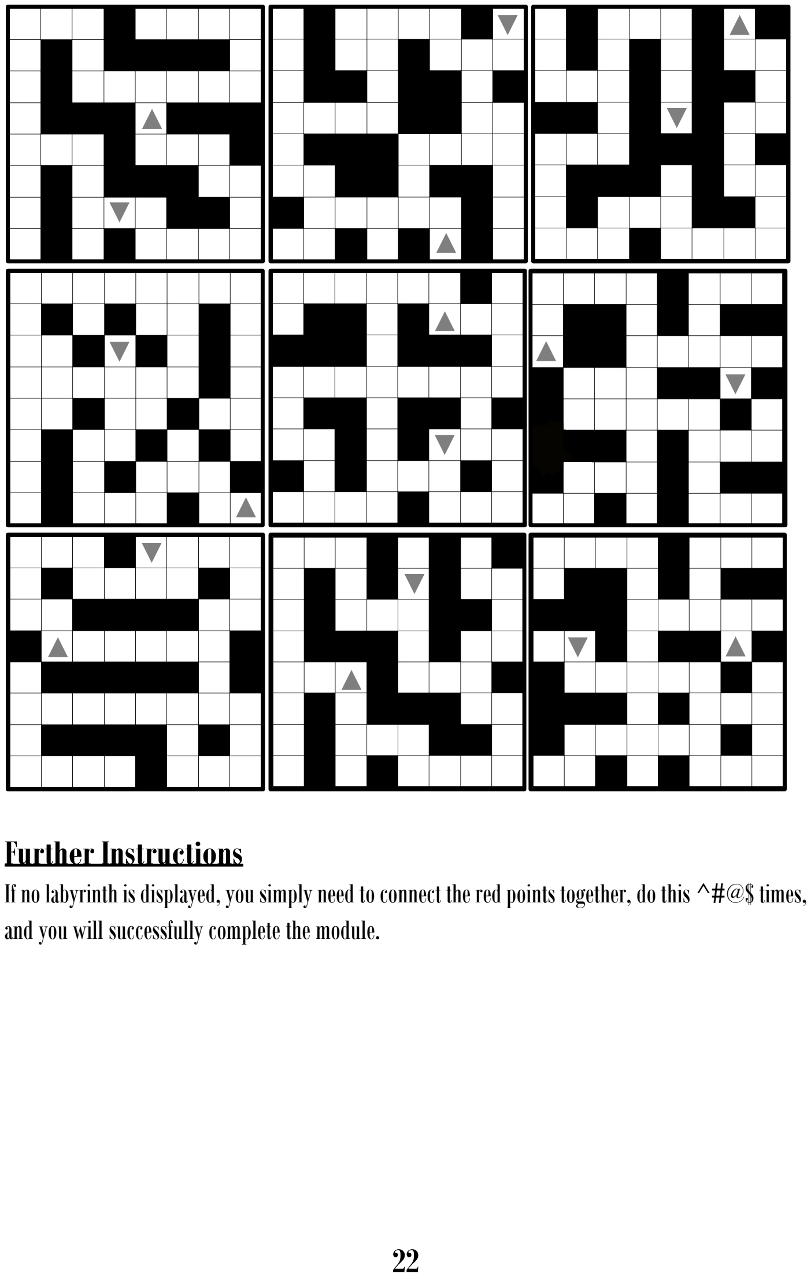
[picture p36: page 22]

22

### Further Instructions

Ifno labyrinth is displayed, you simply need to connect the red points together, do this ^#@$ times, and you will successfully complete the module.

23

## APPENDIX 1: NUMBERSIDENTIFICATION

This appendix will help you to read binary and hexadecimal code. Before we start, we will need to recognize patterns of binary and hexadecimal numbers. Binary is usually represented by a sequence of “bits” that are off or on representing zeros and ones whereas hexadecimal is always represented by numbers and/or capital letter. Here is a table that shows the conversion in binary and hexadecimal of the first 29 numbers.

Decimal | Binary | Hexadecimal
1 | 1 | 1
2 | 10 | 2
3 | 11 | 3
4 | 100 | 4
5 | 101 | 5
6 | 110 | 6
7 | 111 | 7
8 | 1000 | 8
9 | 1001 | 9
10 | 1010 | A
11 | 1011 | B
12 | 1100 | C
13 | 1101 | D
14 | 1110 | E
15 | 1111 | F
16 | 10000 | 10
17 | 10001 | 11
18 | 10010 | 12
19 | 10011 | 13
20 | 10100 | 14
21 | 10101 | 15
22 | 10110 | 16
23 | 10111 | 18
… | … | …

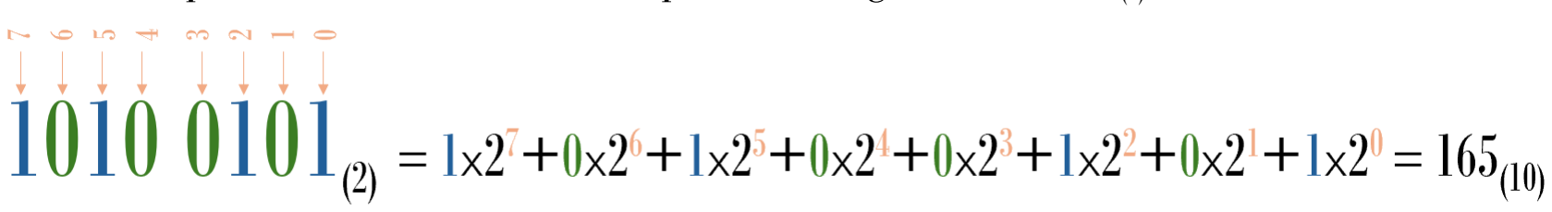
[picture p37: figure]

24

## Conversions:

Each conversions tutorial will be supported by an example to help you understand how they work. Don’t worry, you will be fine!

Binary to decimal:
The conversion of a binary number to a decimal number is straightforward. Each digit of a binary number is a power of two. Here is an example converting the 1010 0101(2) to decimal.

Hexadecimal to decimal:
The conversion of a hexadecimal to a decimal number is pretty much the same principle as binary conversion unless you need to replace zeros and ones with the value of each number/letter. You have values of every letter in hexadecimal in the table above. Here is an example converting AE6(16) to decimal.

25

APPENDIX 9: LEARN HOW TO COUNT.

Counting is a useful skill in many situations. Follow these simple steps to count effectively:

- One by one: Count each item one by one by pointing or touching them.
- Use your fingers: Use your fingers to represent each item you are counting.
- Group in small quantities: If you have many items, group them in small sets to make counting easier.
- Repeat as needed: If you're unsure about the number, feel free to recount. Practice improves accuracy.
- Look closely: Pay attention to details to avoid counting something twice.

Counting is a simple yet important skill. Practice these steps and become a counting pro!

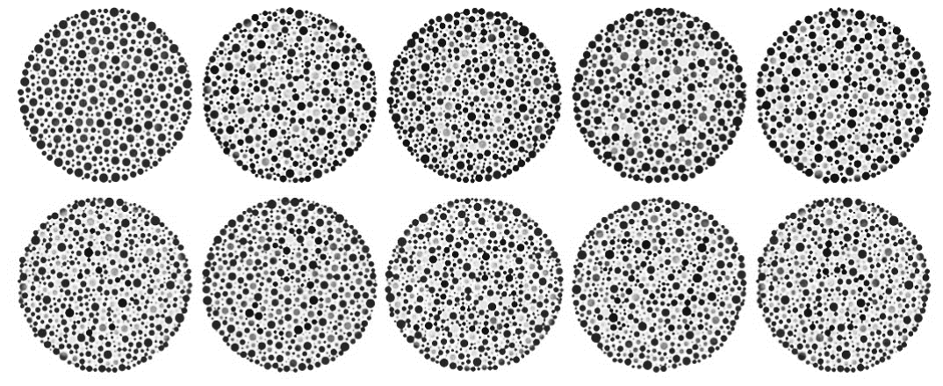
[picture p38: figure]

26

## APPENDIX E: COLOR BLINDNESS DETECTION

I recommend printing this appendix in colour to facilitate the test. This is a classic test. Note down the numbers you think you see in each coloured circle on a sheet of paper. Once finished, send this sheet to the address below:37°14'02.8"N 115°48'08.2"W (the use of a stamp is highly recommended) Then, wait a week for your results (Or indefinitely if you forgot to write your address on the back).

In any case: One sees clearly only with the heart. The essential is invisible to the eyes.

27

## APPENDIX M: MATH BASE

Addition table:

+ | 1 | 2 | 3 | 4 | 5 | 6 | 7 | 8 | 9 | 10 | …
1 | 2 | 3 | 4 | 5 | 6 | 7 | 8 | 9 | 10 | 11 | -
2 | 3 | 4 | 5 | 6 | 7 | 8 | 9 | 10 | 11 | 12 | -
3 | 4 | 5 | 6 | 7 | 8 | 9 | 10 | 11 | 12 | 13 | -
4 | 5 | 6 | 7 | 8 | 9 | 10 | 11 | 12 | 13 | 14 | -
5 | 6 | 7 | 8 | 9 | 10 | 11 | 12 | 13 | 14 | 15 | -
6 | 7 | 8 | 9 | 10 | 11 | 12 | 13 | 14 | 15 | 16 | -
7 | 8 | 9 | 10 | 11 | 12 | 13 | 14 | 15 | 16 | 17 | -
8 | 9 | 10 | 11 | 12 | 13 | 14 | 15 | 16 | 17 | 18 | -
9 | 10 | 11 | 12 | 13 | 14 | 15 | 16 | 17 | 18 | 19 | -
10 | 11 | 12 | 13 | 14 | 15 | 16 | 17 | 18 | 19 | 20 | -
… | - | - | - | - | - | - | - | - | - | -

Mathematical symbol:

Sign | Meaning
∪ | Union: elements that satisfy at least one event
∩ | Intersection: elements that satisfy all events
∨ | Or
∧ | And
¬ | No
→ | So

28

## APPENDIX 26: THE ALPHABET

The alphabet:

In case you don’t remember the alphabet, here is some alphabet that you will maybe need to defuse the Tardis, or just read this manual…
A | B | C | D
E | F | G | H
I | J | K | L
M | N | O | P
Q | R | S | T
U | V | W | X
Y | | Z

29

## APPENDIX NUMBER WHATEVER IT IS

This working? Martha, before I change, here's a list of instructions for when I'm human.

One, don't let me hurt anyone. We can't have that, but you know what humans are like.

Two, don't worry about the Tardis. I'll put it on emergency power so they can't detect it. Just let it hide away.

Four. No, wait a minute…

Three. Not getting involved in big historical events.

Four. You. Don't let me abandon you.

And five. Very important, five. Don't let me eat pears. I HATE PEARS. John Smith is a character I made up, but I won't know that. I'll think I am him, and he might do something stupid like EAT A PEAR. In three months, I don't want to wake up and be human and taste that.

And six. Now I have to talk for around about a minute without hesitation, deviation, or whatever the other thing is. It's like that panel game on Channel Four, (http://www.bbc.co.uk/programmes/b006s5dp) like Rory just pointed out.

However, I'm going to move on and say number seven, and talk about my other favourite band, which is the Housemartins. (https://en.wikipedia.org/wiki/The_Housemartins) I don't know if anyone remembers the Housemartins, but the best gig I ever went to was at the Scottish Exhibition and Conference Centre in about December, it must have been 1990, and the Housemartins were playing, and it was quite simply the best gig I've ever been to. They split up quite soon afterwards; I don't know what that tells you about that particular event.

I'm sitting in the TARDIS now, and I'm going to wind up soon, but not before I make a few strange noises with my mouth that will go somewhere along the lines of bingle bongle, dingle dangle, yikkedy-doo yikkedy-dah ping pong lippytappytoo tah.

And twenty-three. If anything goes wrong, if they find us, Martha, then you know what to do. Open the watch. Everything I am is kept safe in there. Now, I've put a perception filter on it so the human me won't think anything of it. To him, it's just a watch. But don't open it unless you have to. Because once it's open, then the Family will be able to find me. It's all down to you, Martha. Your choice. Oh, and thank you.

30

## APPENDIX: ‘THE DOCTORS’

For configuration Tennant, cut the even-numbered wires.
For the configuration Capaldi, cut the odd-numbered wires.
For configuration Whittaker, do not cut wires that are multiples of 11.
For configuration Smith, cut the wires of the letters that are in the configuration's name. For configuration Baker, do something.
For configuration Hartnell, cut wire 5 if any Tardis window is broken.

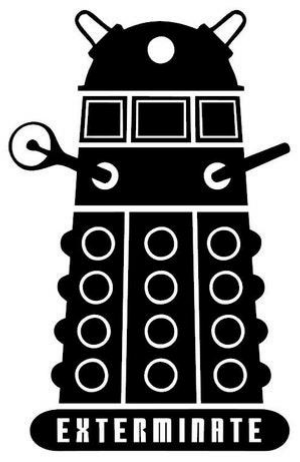
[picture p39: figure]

31

## APPENDIX… GOD! HOW MANY OF THEM ARE THERE!

This is a Dalek.

## Avoid the Daleks…

Stay away from them.
Or you’ll be exterminated.

32

## APPENDIX TETA

Nonsense.

When I say run, run.

Reverse the polarity of the neutron flow.

Would you like a jelly-baby?

Sorry, must dash.

I wonder…

Fine

Probably not the one you expected.

No more.

Fantastic!

Allons-y!

Geronimo!

Clara!

Me fam!

Time travellers are great. Like the best. Like wow!

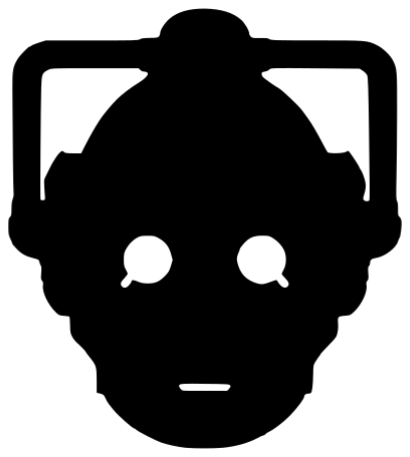
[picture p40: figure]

33

## APPENDIX EPSILON

This is a Cyberman.

## Avoid the Cybermen…

Stay away from them.
Or you’ll be converted.

34

## APPENDIX DAMN!

## Rose, I’m trying to resonate concrete…

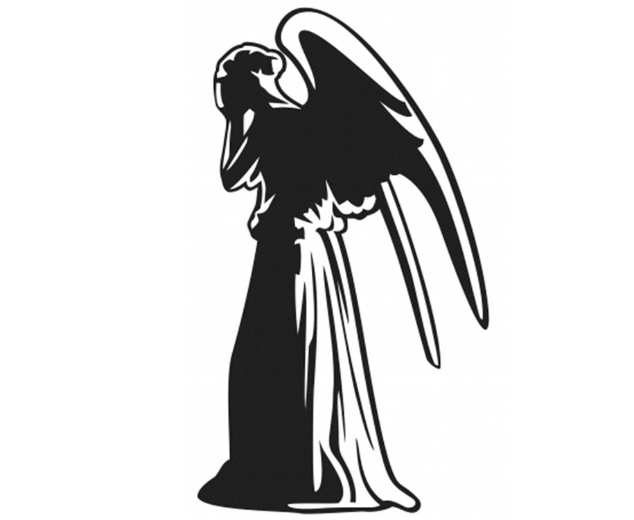
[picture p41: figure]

35

## APPENDIX 202563215

This is a Weeping Angel.

## Avoid the Weeping Angels…

Stay away from them.
And don't blink.
Don't even blink.
Blink and you're dead.

They are fast. Faster than you can believe. Don't turn your back.

### Don't look away. And most of all, don't blink…

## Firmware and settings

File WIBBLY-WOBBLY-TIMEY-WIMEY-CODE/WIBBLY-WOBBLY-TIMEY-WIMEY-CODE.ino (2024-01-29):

#include <Adafruit_NeoPixel.h>
#include <BetterJoystick.h>
#include <LiquidCrystal.h>
#include <Wire.h>
#include <stdint.h>
#include "Tlc5940.h"
#include "SevSeg.h"
#include "special_char.h"


#define DEBUG 1
#define BAUD_RATE 9600
#define RAND_PIN A15

// -- LCD ------------------------------------------------------------------
#define ADD 1
#define SUBSTRACT 0

// BTN LCD CONTROL PIN
#define LEFT_BTN 49
#define RIGHT_BTN 46
#define UP_BTN 47
#define DOWN_BTN 48

// LCD PIN
#define LCD_HEIGHT 2
#define LCD_WIDTH 16
#define RS 7
#define EN 6
#define D4 5
#define D5 4
#define D6 3
#define D7 2

// LCD VARIABLES :
const String words[10] = {
  "DALEKS",
  "CYBERMEN",
  "TIMELORD",
  "TOYMAKER",
  "TARDIS",
  "TIMEANDSPACE",
  "BINARY",
  "LONDON",
  "REGENERATION",
  "SONTAR",
};

int8_t user_cursor = 0;
String selected_word;
String encrypted_word;
uint8_t word_length;
uint8_t center_offset;
uint8_t caesar_offset[2];
char input_word[16] = { '0', '0', '0', '0', '0', '0', '0', '0', '0', '0', '0', '0', '0', '0', '0', '0' };


// LCD FUNCTIONS :
LiquidCrystal lcd(RS, EN, D4, D5, D6, D7);
void detect_button_press();
void wait_btn_release(uint8_t button);
void print_input_word(void);
void update_char_value(uint8_t action);
void check_encryption(void);
String encryption(String word_to_encrypt, uint8_t gap);


// -- TIMER --------------------------------------------------------------
#define DIGIT_NUMBER 4
#define START_TIME 45
#define DISPLAY_BRIGHTNESS 100

#define SEG_D1 33
#define SEG_D2 32
#define SEG_D3 31
#define SEG_D4 30

#define SEG_A 23
#define SEG_B 24
#define SEG_C 25
#define SEG_D 26
#define SEG_E 27
#define SEG_F 28
#define SEG_G 29
#define SEG_DP 22


// TIMER VARIABLES :
uint32_t timer_start = millis();
char formatted_time[5];
const uint8_t DIGIT_PINS[] = { SEG_D1, SEG_D2, SEG_D3, SEG_D4 };
const uint8_t SEGMENT_PINS[] = {
  SEG_A,
  SEG_B,
  SEG_C,
  SEG_D,
  SEG_E,
  SEG_F,
  SEG_G,
  SEG_DP
};

SevSeg display;

// TIMER FUNCTIONS :
void decrement_time(void);
void time_blink(void);


// -- JOYSTICK MODULE ------------------------------------------------------
#define LED_COUNT 16
#define LED_PIN 44
#define MAX_BRIGHTNESS 75
#define RAND_PIN A15

#define J_X A1
#define J_Y A0

#define J_UP 1
#define J_DOWN 2
#define J_LEFT 3
#define J_RIGHT 4

#define ACTION -1
#define ERROR 1
#define SUCCESS 0
#define ACTION_ANIM_DELAY 50

#define DELAYED_DISPLAY 200
#define INSTANT_DISPLAY 0


// JOYSTICK VARIABLE :
int decimal_numbers[] = { 25772, 4757, 29294, 19348, 31011, 32063, 17884, 35933, 727, 29973 };
uint8_t BUILTIN_JOYSTICK_SEQ[10][4] = {
  { J_LEFT, J_UP, J_RIGHT, J_UP },
  { J_UP, J_RIGHT, J_LEFT, J_DOWN },
  { J_DOWN, J_RIGHT, J_UP, J_RIGHT },
  { J_LEFT, J_DOWN, J_UP, J_RIGHT },
  { J_RIGHT, J_LEFT, J_UP, J_DOWN },
  { J_DOWN, J_LEFT, J_RIGHT, J_UP },
  { J_RIGHT, J_DOWN, J_UP, J_LEFT },
  { J_UP, J_LEFT, J_UP, J_RIGHT },
  { J_LEFT, J_DOWN, J_RIGHT, J_UP },
  { J_DOWN, J_RIGHT, J_LEFT, J_DOWN },
};


int selected_joystick_number;
int8_t trig_rotation;
uint8_t selected_joystick_seq;
uint8_t joystick_input_seq[4];
uint8_t joystick_seq_index = 0;

// JOYSTICK FUNCTIONS :

Adafruit_NeoPixel strip(LED_COUNT, LED_PIN, NEO_GRB + NEO_KHZ800);
Joystick joystick(J_X, J_Y, -1);
void blink_animation(uint8_t blink_count, uint16_t duration, int8_t effect_id);
void show_binary_on_screen(int binary, int8_t trig_rotation, uint16_t effect_delay);
void add_direction_to_seq(uint8_t direction);
bool check_seq(uint8_t seq_id);
void event_joystick_listener(void);
void wait_joystick_release(void);
void idle_animation(void);
void check_win(void);


// -- WIRE MODULE ----------------------------------------------------------
#define TERM_COUNT 8
#define A_PIN 42
#define B_PIN 43
#define C_PIN 40
#define D_PIN 41
#define E_PIN 38
#define F_PIN 36
#define G_PIN 39
#define H_PIN 37

#define RED_LED_PIN 34
#define GREEN_LED_PIN 35

#define CUTTED 1
#define CONNECTED 0

// WIRE VARIABLE :
const uint8_t TERMINAL_PINS[8] = { A_PIN, B_PIN, C_PIN, D_PIN, E_PIN, F_PIN, G_PIN, H_PIN };
const uint8_t BUILTIN_WIRE_STATES[8] = { CUTTED, CUTTED, CONNECTED, CONNECTED, CUTTED, CONNECTED, CONNECTED, CUTTED };
uint8_t current_wire_state[8];

// WIRE FUNCTIONS :
void wire_disconnect_handler(void);
void check_wire_connection(void);


// -- BUZZER MODULE ------------------------------------------------------------
#define BUZZER_PIN 12

#define SOUND_ON_TIMER_TICK 1
#define TICK_FREQ 1000

#define SOUND_ON_ACTION 1
#define ACTION_FREQ 300

#define SOUND_ON_EVENT 1
#define SUCCESS_FREQ 783
#define ERROR_FREQ 200


// -- GYRO MODULE ------------------------------------------------------------
#define GYRO_DEFUSE_PIN 11

// GYRO FUNCTIONS :
void check_gyro_defuse_state(void);


// -- WIN VARIABLES ------------------------------------------------------------
uint8_t joystick_is_defused = 0;
uint8_t lcd_is_defused = 0;
uint8_t gyro_is_defused = 0;
uint8_t wire_is_defused = 0;



void setup() {
  Serial.begin(BAUD_RATE);
  randomSeed(analogRead(RAND_PIN));

  if (DEBUG) {
    Serial.println("\n-- DEFUSE INFORMATION ---------------------------------");
  }

  // -- LCD --------------------------------------------------------------------
  lcd.begin(LCD_WIDTH, LCD_HEIGHT);
  pinMode(UP_BTN, INPUT_PULLUP);
  pinMode(DOWN_BTN, INPUT_PULLUP);
  pinMode(LEFT_BTN, INPUT_PULLUP);
  pinMode(RIGHT_BTN, INPUT_PULLUP);

  uint8_t selected_word_id = random(10);
  selected_word = words[selected_word_id];
  encrypted_word = encryption(selected_word, generate_caesar_offset());
  word_length = encrypted_word.length();
  center_offset = (16 - word_length) / 2;

  lcd.setCursor(center_offset, 0);
  lcd.print(encrypted_word);

  // -- TIMER ------------------------------------------------------------------
  display.begin(COMMON_CATHODE, DIGIT_NUMBER, DIGIT_PINS, SEGMENT_PINS);
  display.setBrightness(DISPLAY_BRIGHTNESS);

  // -- JOYSTICK ---------------------------------------------------------------
  strip.begin();
  strip.show();
  strip.setBrightness(MAX_BRIGHTNESS);
  selected_joystick_seq = random(0, 10);
  selected_joystick_number = decimal_numbers[random(sizeof(decimal_numbers) / sizeof(decimal_numbers[0]))];
  trig_rotation = random(0, 2);

  show_binary_on_screen(selected_joystick_number, trig_rotation, DELAYED_DISPLAY);


  // -- WIRE -------------------------------------------------------------------
  pinMode(RED_LED_PIN, OUTPUT);
  pinMode(GREEN_LED_PIN, OUTPUT);

  for (uint8_t pin_index = 0; pin_index < TERM_COUNT; pin_index++) {
    pinMode(TERMINAL_PINS[pin_index], INPUT_PULLUP);
  }

  // -- BUZZER -----------------------------------------------------------------
  pinMode(BUZZER_PIN, OUTPUT);


  // -- GYRO -------------------------------------------------------------------
  pinMode(GYRO_DEFUSE_PIN, INPUT);

  // -- DEBUG ------------------------------------------------------------------
  if (DEBUG) {
    Serial.print("LCD MODULE SOLUTION : ");
    Serial.println(selected_word);
    Serial.print("JOYSTICK SEQUENCE SOLUTION : ");

    for (uint8_t index = 0; index < 4; index++) {

      switch (BUILTIN_JOYSTICK_SEQ[selected_joystick_seq][index]) {
        case J_UP:
          Serial.print("UP, ");
          break;
        case J_DOWN:
          Serial.print("DOWN, ");
          break;
        case J_LEFT:
          Serial.print("LEFT, ");
          break;
        case J_RIGHT:
          Serial.print("RIGHT, ");
          break;
        default:
          Serial.print("\nERROR, RESET NEDDED \n");
          break;
      }
    }

    Serial.println("\n\n");
  }



  Serial.print("1 -> ");
  Serial.println(digitalRead(A_PIN));
  Serial.print("2 -> ");
  Serial.println(digitalRead(B_PIN));
  Serial.print("3 -> ");
  Serial.println(digitalRead(C_PIN));
  Serial.print("4 -> ");
  Serial.println(digitalRead(D_PIN));
  Serial.print("5 -> ");
  Serial.println(digitalRead(E_PIN));
  Serial.print("6 -> ");
  Serial.println(digitalRead(F_PIN));
  Serial.print("7 -> ");
  Serial.println(digitalRead(G_PIN));
  Serial.print("8 -> ");
  Serial.println(digitalRead(H_PIN));
}

void loop() {
  // TIMER :
  decrement_time();

  // LCD :
  detect_button_press();
  lcd.setCursor(center_offset + user_cursor, 1);
  lcd.cursor();
  check_encryption();

  // JOYSTICK :
  event_joystick_listener();
  check_win();

  // WIRE :
  wire_disconnect_handler();
  check_wire_connection();

  // GYRO :
  check_gyro_defuse_state();

  // DEFUSE :
  check_defused_state();
}


// -- TIMER FUNCTIONS ----------------------------------------------------------

void decrement_time(void) {
  /*
  Function that update the seven segment display to the current ellapsed time. 
  */

  // Calculate how much time left according to the elapsed time.
  static uint8_t time_is_finished = 0;
  static uint16_t last_second_value = 0;
  uint32_t elapsed_time = millis() - timer_start;
  uint16_t total_elapsed_seconds = (START_TIME * 60) - (elapsed_time / 1000);

  if (time_is_finished) {
    time_blink();
    return;
  }

  if (SOUND_ON_TIMER_TICK && last_second_value != total_elapsed_seconds) {
    tone(BUZZER_PIN, TICK_FREQ, 25);
    last_second_value = total_elapsed_seconds;
  }

  // Calculate elapsed minutes and seconds from total_elapsed_seconds
  uint8_t minutes = total_elapsed_seconds / 60;
  uint8_t seconds = total_elapsed_seconds % 60;

  // Format the elapsed time, add zeros in front of minutes and seconds smaller than 9.
  if (minutes < 10 && seconds < 10) {
    sprintf(formatted_time, "0%d.0%d", minutes, seconds);
  } else if (minutes < 10) {
    sprintf(formatted_time, "0%d.%d", minutes, seconds);
  } else if (seconds < 10) {
    sprintf(formatted_time, "%d.0%d", minutes, seconds);
  } else {
    sprintf(formatted_time, "%d.%d", minutes, seconds);
  }

  // Check if the time is finished.
  if (total_elapsed_seconds <= 0) {

    // Time finished.
    time_is_finished = 1;
  }

  // display and refresh.
  display.setChars(formatted_time);
  display.refreshDisplay();
}


void time_blink(void) {
  /*
  Function that create the animation when the time is finished. 
  */
  uint16_t current_time = millis() / 1000;

  if (current_time % 2 == 0) {
    display.setChars("  .  ");
    display.refreshDisplay();
    return;
  }

  display.setChars(formatted_time);
  display.refreshDisplay();
}


// -- DEFUSE -------------------------------------------------------------------
void check_defused_state(void) {
  /*
  Function that check if every module has been defused.  
  */

  if (joystick_is_defused && lcd_is_defused && wire_is_defused && gyro_is_defused) {
    // Sound animation on win.
    if (SOUND_ON_EVENT) {
    }

    for (;;) {
      time_blink();
    }
  }
}


// -- LCD FUNCTIONS ------------------------------------------------------------
uint8_t generate_caesar_offset(void) {
  /*
  Function that generate 2 random offsets and print it on the screen according to special characters.  
  */
  uint8_t first_offset = random(5, 26);
  uint8_t second_offset = random(1, first_offset - 1);

  print_offset_glyph(first_offset, second_offset);
  return first_offset - second_offset;
}


void print_offset_glyph(uint8_t first_offset, uint8_t second_offset) {
  if (DEBUG) {
    Serial.print("FIRST_GLYPH_INDEX = ");
    Serial.println(first_offset);
    Serial.print("SECOND_GLYPH_INDEX = ");
    Serial.println(second_offset);
    Serial.print("TOTAL CRYPT OFFSET = ");
    Serial.println(first_offset - second_offset);
  }

  lcd.createChar(0, offset_glyph[first_offset]);
  lcd.createChar(1, offset_glyph[second_offset]);

  lcd.setCursor(0, 0);
  lcd.write(byte(0));

  lcd.setCursor(LCD_WIDTH - 1, 0);
  lcd.write(byte(1));
}

void detect_button_press(void) {
  /*
  Function that handle button press detection and actions. 
  */

  if (lcd_is_defused) {
    return;
  }

  if (digitalRead(UP_BTN) == 0) {
    // Up button pressed, cycle up letters.
    if (SOUND_ON_ACTION) { tone(BUZZER_PIN, ACTION_FREQ, 50); }
    update_char_value(ADD);
    wait_btn_release(UP_BTN);
  }

  if (digitalRead(DOWN_BTN) == 0) {
    // Down button pressed, cycle down letters.
    if (SOUND_ON_ACTION) { tone(BUZZER_PIN, ACTION_FREQ, 50); }
    update_char_value(SUBSTRACT);
    wait_btn_release(DOWN_BTN);
  }

  if (digitalRead(LEFT_BTN) == 0) {
    // Left button pressed, move the cursor to the left.
    if (SOUND_ON_ACTION) { tone(BUZZER_PIN, ACTION_FREQ, 50); }
    wait_btn_release(LEFT_BTN);
    user_cursor--;

    // Check if the cursor is out of bound.
    if (user_cursor < 0) {
      user_cursor = word_length - 1;
    }
  }

  if (digitalRead(RIGHT_BTN) == 0) {
    // Right button pressed, move the cursor to the right.
    if (SOUND_ON_ACTION) { tone(BUZZER_PIN, ACTION_FREQ, 50); }
    wait_btn_release(RIGHT_BTN);
    user_cursor++;

    // Check if the cursor is out of bound.
    if (user_cursor >= word_length) {
      user_cursor = 0;
    }
  }
}


void wait_btn_release(uint8_t button) {
  /*
  Function that wait the button to be released and execute action that not depend
  on which button is pressed. 
  */
  while (digitalRead(button) == 0) {
    decrement_time();
  }

  // Execute actions.
  print_input_word();
}


void print_input_word(void) {
  /*
  Function that print letter that the user selected. 
  */
  for (uint8_t index = 0; index < word_length; index++) {
    lcd.setCursor(center_offset + index, 1);

    if (input_word[index] < 65 || input_word[index] > 90) {
      // If the character is not a letter, print a blank character.
      lcd.write(' ');
      continue;
    }

    // Print the character.
    lcd.write(input_word[index]);
  }
}


void update_char_value(uint8_t action) {
  /*
  Function that increment or decrement the character value at a specific index. 
  */

  if (input_word[user_cursor] < 65 || input_word[user_cursor] > 90) {
    // If character is not initialised, initialise it.
    input_word[user_cursor] = (action == ADD) ? 65 : 90;
    return;
  }

  if (action == ADD) {
    // Add one to the current selected character.
    input_word[user_cursor]++;

    // Check if the character value is out of bound.
    if (input_word[user_cursor] > 90) {
      input_word[user_cursor] = 65;
    }

    return;
  }

  // Substract one to the current selected character.
  input_word[user_cursor]--;

  // Check if the character value is out of bound.
  if (input_word[user_cursor] < 65) {
    input_word[user_cursor] = 90;
  }

  return;
}


void check_encryption(void) {
  /*
  Function that check if the input sequence is correct.  
  */

  static uint8_t is_defused = 0;

  if (is_defused) {
    return;
  }

  for (uint8_t index = 0; index < word_length; index++) {
    // Check each character if one doesn't match, abort.
    if (selected_word[index] != input_word[index]) {
      return;
    }
  }

  lcd.noCursor();
  delay(500);
  lcd.setCursor(0, 0);
  lcd.print("    unlocked    ");

  if (SOUND_ON_EVENT) {
    // Sound animation on validation.

    uint8_t RHYTHM = 150;
    tone(BUZZER_PIN, 783, RHYTHM - 50);
    delay(RHYTHM);
    tone(BUZZER_PIN, 783, RHYTHM - 50);
    delay(RHYTHM);
    tone(BUZZER_PIN, 783, RHYTHM - 50);
    delay(RHYTHM);

    tone(BUZZER_PIN, 1046, RHYTHM);
    delay(RHYTHM * 2);
    tone(BUZZER_PIN, 783, RHYTHM - 50);
    delay(RHYTHM);
    tone(BUZZER_PIN, 1046, RHYTHM * 3);
    delay(RHYTHM * 3);
  }

  is_defused = 1;

  // Set win variable to true.
  lcd_is_defused = 1;
  if (DEBUG) { Serial.println("LCD HAS BEEN DEFUSED!!!"); }
}


String encryption(String word_to_encrypt, uint8_t gap) {
  /*
  Function that encrypt a word using cesar algorithm. 
  */

  uint8_t word_length = word_to_encrypt.length();
  char encrypt_word[word_length];

  // Add an offset to each letter of the word to encrypt.
  for (uint8_t index = 0; index < word_length; index++) {
    encrypt_word[index] = ((word_to_encrypt[index] - 'A' + gap) % 26) + 'A';
  }

  return encrypt_word;
}


// -- JOYSTICK FUNCTIONS -------------------------------------------------------
void check_win(void) {
  static uint8_t is_defused = 0;

  if (is_defused) {
    idle_animation();
    return;
  }

  if (joystick_seq_index > 3) {
    joystick_seq_index = 0;

    if (check_seq(selected_joystick_seq)) {
      blink_animation(3, 200, SUCCESS);
      idle_animation();

      is_defused = 1;
      joystick_is_defused = 1;

      if (DEBUG) { Serial.println("JOYSTICK HAS BEEN DEFUSED!!!"); }
      return;
    }

    blink_animation(3, 200, ERROR);
    show_binary_on_screen(selected_joystick_number, trig_rotation, INSTANT_DISPLAY);
    return;
  }
}


void show_binary_on_screen(int binary, int8_t trig_rotation, uint16_t effect_delay) {
  uint8_t offset = 0;
  uint32_t color = strip.Color(120, 0, 255);

  if (!trig_rotation) {
    offset = 14;
    color = strip.Color(0, 0, 255);
  }

  strip.setPixelColor(0, color);


  for (int bit_position = 0; bit_position < LED_COUNT - 1; bit_position++) {
    int bit_value = (decimal_numbers[selected_joystick_seq] >> bit_position) & 1;

    if (bit_value == 1) {
      strip.setPixelColor(abs(offset - bit_position) + 1, 255, 255, 255);
      delay(effect_delay);
    }

    strip.show();
  }
}


void blink_animation(uint8_t blink_count, uint16_t duration, int8_t effect_id) {
  display.setChars("    ");
  display.refreshDisplay();

  uint32_t color;
  uint16_t sound_freq = 0;

  switch (effect_id) {
    case -1:
      // ACTION.
      color = strip.Color(0, 0, 0);
      break;

    case 0:
      // SUCCESS.
      color = strip.Color(22, 218, 28);
      sound_freq = SUCCESS_FREQ;
      break;

    case 1:
      // ERROR.
      color = strip.Color(200, 0, 0);
      sound_freq = ERROR_FREQ;
      break;

    default:
      return;
  }

  for (uint8_t count = 0; count < blink_count; count++) {
    strip.clear();
    strip.show();
    if (SOUND_ON_EVENT) { tone(BUZZER_PIN, sound_freq, duration); }
    delay(duration);
    strip.fill(color, 0, LED_COUNT);
    strip.show();
    delay(duration);
  }

  strip.clear();
  strip.show();
}


void add_direction_to_seq(uint8_t direction) {
  blink_animation(1, ACTION_ANIM_DELAY, ACTION);
  show_binary_on_screen(selected_joystick_number, trig_rotation, INSTANT_DISPLAY);

  joystick_input_seq[joystick_seq_index] = direction;
  joystick_seq_index++;

  return;
}


bool check_seq(uint8_t seq_id) {
  for (uint8_t index = 0; index < 4; index++) {
    if (joystick_input_seq[index] != BUILTIN_JOYSTICK_SEQ[seq_id][index]) {
      // One direction does't match.
      if (DEBUG) {
        Serial.print(joystick_input_seq[index]);
        Serial.print(" != ");
        Serial.println(BUILTIN_JOYSTICK_SEQ[seq_id][index]);
      }

      return false;
    }
  }

  return true;
}


void event_joystick_listener() {
  /*
  Function that handle joystick direction event. 
  */

  if (joystick_is_defused) {
    return;
  }

  switch (joystick.facingDirection()) {
    case DIRECTION::UP:
      DEBUG ? Serial.print("UP, ") : Serial.print("");

      add_direction_to_seq(J_UP);
      wait_joystick_release();
      break;

    case DIRECTION::DOWN:
      DEBUG ? Serial.print("DOWN, ") : Serial.print("");

      add_direction_to_seq(J_DOWN);
      wait_joystick_release();
      break;

    case DIRECTION::LEFT:
      DEBUG ? Serial.print("LEFT, ") : Serial.print("");

      add_direction_to_seq(J_LEFT);
      wait_joystick_release();
      break;

    case DIRECTION::RIGHT:
      DEBUG ? Serial.print("RIGHT, ") : Serial.print("");

      add_direction_to_seq(J_RIGHT);
      wait_joystick_release();
      break;
  }
}

void wait_joystick_release() {
  /*
  Function that wait the joystick to be released.
  */

  if (SOUND_ON_ACTION) { tone(BUZZER_PIN, ACTION_FREQ, 50); }

  while (joystick.facingDirection() != DIRECTION::CENTER) {
    // Wait...
    decrement_time();
  }

  // Joystick released.
  return;
}

void idle_animation() {
  static uint8_t is_set = 0;

  if (is_set) {
    return;
  }

  // Set strip color to solid green.
  strip.fill(strip.Color(22, 218, 28), 0, LED_COUNT);
  strip.show();

  // Sound animation.
  if (SOUND_ON_EVENT) {
    uint8_t RHYTHM = 150;
    tone(BUZZER_PIN, 783, RHYTHM - 50);
    delay(RHYTHM);
    tone(BUZZER_PIN, 783, RHYTHM - 50);
    delay(RHYTHM);
    tone(BUZZER_PIN, 783, RHYTHM - 50);
    delay(RHYTHM);

    tone(BUZZER_PIN, 1046, RHYTHM);
    delay(RHYTHM * 2);
    tone(BUZZER_PIN, 783, RHYTHM - 50);
    delay(RHYTHM);
    tone(BUZZER_PIN, 1046, RHYTHM * 3);
    delay(RHYTHM * 3);
  }

  // No repeat.
  is_set = 1;
}


// -- WIRE FUNCTIONS -----------------------------------------------------------
void wire_disconnect_handler() {
  /*
  Function that update the wire connection in the table. 
  */

  // Check if the module is already defused.
  if (wire_is_defused) {
    return;
  }

  // Loop through each connection.
  for (uint8_t index = 0; index < TERM_COUNT; index++) {
    // Update the value.
    current_wire_state[index] = digitalRead(TERMINAL_PINS[index]);
  }
}


void check_wire_connection() {
  /*
  Function that check if correct wire were cut and set the win. 
  */

  static uint8_t is_defused = 0;

  // If the module is defused, activate green led.
  if (is_defused) {
    return;
  }

  // Else check if the connection are right.
  digitalWrite(RED_LED_PIN, HIGH);
  digitalWrite(GREEN_LED_PIN, LOW);

  // Loop through each connection.
  for (uint8_t index = 0; index < TERM_COUNT; index++) {
    if (current_wire_state[index] != BUILTIN_WIRE_STATES[index]) {
      return;
    }
  }

  // Every connection is correct.
  is_defused = 1;
  wire_is_defused = 1;
  digitalWrite(RED_LED_PIN, LOW);
  digitalWrite(GREEN_LED_PIN, HIGH);
  if (DEBUG) { Serial.println("WIRE HAS BEEN DEFUSED!!!"); }
}
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
